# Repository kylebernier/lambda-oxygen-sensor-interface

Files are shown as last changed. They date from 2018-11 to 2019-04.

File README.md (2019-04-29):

# Lambda Oxygen Sensor Interface

This repository contains all code, pcb design, and verification scripts performed for the Lambda Oxygen Sensor Interface. This device uses a Bosch LSU 4.9 paired with a Bosch CJ125 to measure the oxygen content of an engine's exhaust. The value output by the device is the lambda value, which is the ratio between the stoichiometric air/fuel ratio and the air/fuel ratio measured by the sensor. The values output are between 0.65 and 1.36 and are proportional to 0 to 5V DC. A serial UART interface also outputs the lambda value, the temperature, and the voltage the sensor is being set to.  

## Repository Structure
- All code for the actual device can be found in the `code` folder.
- All simulations for hardware and software algortihms can be found in the `sim` folder.
- All PCB design files can be found in the `pcb` folder.
- All scripts and data for verifying results can be found in the `verification` folder.

## Reference Documents

* [STM32L476VG Datasheet](https://www.st.com/resource/en/datasheet/stm32l476vg.pdf)
* [STM32L475RC Datasheet](https://www.st.com/resource/en/datasheet/stm32l475rc.pdf)
* [STM32L4xx Reference Manual](https://www.st.com/content/ccc/resource/technical/document/reference_manual/02/35/09/0c/4f/f7/40/03/DM00083560.pdf/files/DM00083560.pdf/jcr:content/translations/en.D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)
* [STM32L4xx Hal Reference Manual](https://www.st.com/content/ccc/resource/technical/document/user_manual/63/a8/8f/e3/ca/a1/4c/84/DM00173145.pdf/files/DM00173145.pdf/jcr:content/translations/en.DM0017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)
* [CJ125 Datasheet](http://www.bosch-semiconductors.com/media/automotive_systems_ics/pdf_1/ic_engine_management/bosch_ic_cj125.pdf)
* [LSU 4.9 Datasheet](https://www.ecotrons.com/files/Bosch_LSU49_Tech_Info.pdf)

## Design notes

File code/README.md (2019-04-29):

# Code

## Code Algorithm

The code controls a STM32L4 microcontroller on a Lambda Oxygen Sensor Interface board.

### Modules Being Used
All modules and their respective GPIO pins can be found in `hw_map.h`
* ADC: ADC1 on channels 8, 11, 12, 16 
* DMA: DMA1 on channel 1
* SPI: SPI2
* DAC: DAC1 on channel 2
* PWM: TIM8 on channel 2, IRQ on channel 1
* UART: USART1

## Build Instructions

### Required Packages
* arm-none-eabi-gcc
* arm-none-eabi-gdb
* arm-none-eabi-binutils
* openOCD

### Recommended Packages
* Visual Studio Code
    * Cortex-Debug Extension

### Compiling
* Run `make`

    or

* Run `Debug STM32L4` debugger in VSCode

### Flashing
* Run `openocd -f openocd.cfg -c "program bin/main.elf verify reset exit"`

    or

* Run `Debug STM32L4` debugger in VSCode

### Debugging
* Use gdb with openOCD

    or

* Run `Debug STM32L4` debugger in VSCode

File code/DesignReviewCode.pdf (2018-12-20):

adc.c | Page 1 of 4
/**
* @file adc.c
* @author Kyle Bernier
* @author Daeghan Elkin
* @date 2018 July 15
*
* @brief Provides basic ADC functionality */

#include "stm32l4xx_ll_dma.h"

#include "adc.h"

/**
* @brief Initialize DMA for the ADC
*
* @param values Array to store ADC values
* @param numValues Number of values in values array *
* @retval None
*/
static void ADC_Init_DMA(uint16_t * values, int numValues);

/** @brief Delay between ADC end of calibration and ADC enable */
#define ADC_DELAY_CALIB_ENABLE_CPU_CYCLES (LL_ADC_DELAY_CALIB_ENABLE_ADC_CYCLES * 32)

/** @brief Number of possible ADC channels */
#define ADC_NUM_CHANNELS 24

/** @brief Array of ADC channels */ uint32_t ADC_CHANNELS[ADC_NUM_CHANNELS] = { LL_ADC_CHANNEL_0,
LL_ADC_CHANNEL_1,
LL_ADC_CHANNEL_2,
LL_ADC_CHANNEL_3,
LL_ADC_CHANNEL_4,
LL_ADC_CHANNEL_5,
LL_ADC_CHANNEL_6,
LL_ADC_CHANNEL_7,
LL_ADC_CHANNEL_8,
LL_ADC_CHANNEL_9,
LL_ADC_CHANNEL_10,
LL_ADC_CHANNEL_11,
LL_ADC_CHANNEL_12,
LL_ADC_CHANNEL_13,
LL_ADC_CHANNEL_14,
LL_ADC_CHANNEL_15,
LL_ADC_CHANNEL_16,
LL_ADC_CHANNEL_VREFINT, | // ADC1 Only, Uses Channel 0
LL_ADC_CHANNEL_TEMPSENSOR, | // ADC1 or ADC3
LL_ADC_CHANNEL_VBAT, | // ADC1 or ADC3
LL_ADC_CHANNEL_DAC1CH1_ADC2, | // ADC2 Only
LL_ADC_CHANNEL_DAC1CH2_ADC2, | // ADC2 Only
LL_ADC_CHANNEL_DAC1CH1_ADC3, | // ADC3 Only, Uses Channel 14
LL_ADC_CHANNEL_DAC1CH2_ADC3 | // ADC3 Only, Uses Channel 15
};

/** @brief Array of ADC channel ranks */
uint32_t ADC_RANKS[16] = {
LL_ADC_REG_RANK_1,
LL_ADC_REG_RANK_2,
LL_ADC_REG_RANK_3,
LL_ADC_REG_RANK_4,
LL_ADC_REG_RANK_5,
LL_ADC_REG_RANK_6,
LL_ADC_REG_RANK_7,
LL_ADC_REG_RANK_8,
LL_ADC_REG_RANK_9,
LL_ADC_REG_RANK_10,
LL_ADC_REG_RANK_11,
LL_ADC_REG_RANK_12,
LL_ADC_REG_RANK_13,

adc.c | Page 2 of 4
LL_ADC_REG_RANK_14,
LL_ADC_REG_RANK_15,
LL_ADC_REG_RANK_16
};

/**
* @brief DMA transfer value
* 0: DMA transfer is not completed @n
* 1: DMA transfer is completed @n
* 2: DMA transfer has not been started yet (initial state) */
volatile uint8_t dmaTransferStatus = 2;

/**
* @brief ADC group sequence conversion value
* 0: ADC group regular sequence conversions are not completed * 1: ADC group regular sequence conversions are completed */
volatile uint8_t adcConversionStatus = 0;

/* Initialize ADC with DMA*/
void Init_ADC(uint32_t channels, uint16_t * values, int numValues) {
int i, j;

// Check if the ADC is already enabled
if (LL_ADC_IsEnabled(ADCx_BASE)) { return;
}

// Initialize DMA for the ADC
ADC_Init_DMA(values, numValues);

// Enable ADC interrupts
// Set the ADC IRQ to a greater priority than the DMA IRQ NVIC_SetPriority(ADCx_IRQ, 0); NVIC_EnableIRQ(ADCx_IRQ);

// Enable the ADC clock
ADCx_CLK_ENABLE();

// Set the ADC clock
LL_ADC_SetCommonClock(__LL_ADC_COMMON_INSTANCE(ADCx_BASE), LL_ADC_CLOCK_SYNC_PCLK_DIV2);

// Enable the internal ADC channels LL_ADC_SetCommonPathInternalCh(__LL_ADC_COMMON_INSTANCE(ADCx_BASE), (LL_ADC_PATH_INTERNAL_VRE
FINT | LL_ADC_PATH_INTERNAL_TEMPSENSOR | LL_ADC_PATH_INTERNAL_VBAT));

// Delay for the internal ADC channels to stablize
// The temperature sensor takes the longest time to stabalize
i = ((LL_ADC_DELAY_TEMPSENSOR_STAB_US * (SystemCoreClock / (100000 * 2))) / 10); while (i != 0) {
i--;
}

// Set the ADC to have a external timer trigger source LL_ADC_REG_SetTriggerSource(ADCx_BASE, LL_ADC_REG_TRIG_EXT_TIM8_TRGO);

// Set the ADC to trigger on the rising edge LL_ADC_REG_SetTriggerEdge(ADCx_BASE, LL_ADC_REG_TRIG_EXT_RISING);

// Set the ADC to perform a single conversion LL_ADC_REG_SetContinuousMode(ADCx_BASE, LL_ADC_REG_CONV_SINGLE);

// Set the ADC conversion data transfer LL_ADC_REG_SetDMATransfer(ADCx_BASE, LL_ADC_REG_DMA_TRANSFER_UNLIMITED);

// Set the ADC overrun behavior
LL_ADC_REG_SetOverrun(ADCx_BASE, LL_ADC_REG_OVR_DATA_OVERWRITTEN);

// Set the ADC sequencer length

adc.c | Page 3 of 4
LL_ADC_REG_SetSequencerLength(ADCx_BASE, numValues - 1);

// Enable specified ADC channels
for (i = 0, j = 0; i < ADC_NUM_CHANNELS; i++) {
if (channels & (1 << i)) {
LL_ADC_REG_SetSequencerRanks(ADCx_BASE, ADC_RANKS[j], ADC_CHANNELS[i]); LL_ADC_SetChannelSamplingTime(ADCx_BASE, ADC_CHANNELS[i], ADCx_SAMPLERATE); j++;
}
if (j >= numValues || j >= 16) break;
}

// Enable ADC interupts for conversion completion LL_ADC_EnableIT_EOS(ADCx_BASE);

// Enable ADC interupts for overrun LL_ADC_EnableIT_OVR(ADCx_BASE);

// Disable the ADC deep power down mode LL_ADC_DisableDeepPowerDown(ADCx_BASE);

// Enable the ADC internal voltage regulator LL_ADC_EnableInternalRegulator(ADCx_BASE);

// Delay for the ADC internal voltage regulator to stabilize
i = ((LL_ADC_DELAY_INTERNAL_REGUL_STAB_US * (SystemCoreClock / (100000 * 2))) / 10); while (i != 0) {
i--;
}

// Start the ADC calibration LL_ADC_StartCalibration(ADCx_BASE, LL_ADC_SINGLE_ENDED);

// Wait for the ADC calibration to finish
while (LL_ADC_IsCalibrationOnGoing(ADCx_BASE) != 0);

// Delay to allow ADC calibration to enable
i = (ADC_DELAY_CALIB_ENABLE_CPU_CYCLES >> 1); while (i != 0) {
i--;
}

// Enable the ADC
LL_ADC_Enable(ADCx_BASE);

// Wait for the ADC to be ready
while (LL_ADC_IsActiveFlag_ADRDY(ADCx_BASE) == 0);

// Start the ADC conversion LL_ADC_REG_StartConversion(ADCx_BASE);
}

static void ADC_Init_DMA(uint16_t *values, int numValues) {
// Enable DMA interrupts
// Set the DMA IRQ to a lower priority than the ADC IRQ NVIC_SetPriority(DMAx_IRQ, 1); NVIC_EnableIRQ(DMAx_IRQ);

// Enable the DMA clock
DMAx_CLK_ENABLE();

// Configure the DMA transfer LL_DMA_ConfigTransfer(DMAx_BASE, DMAx_CHANNEL, LL_DMA_DIRECTION_PERIPH_TO_MEMORY | LL_DMA_MODE_CIRCULAR |
LL_DMA_PERIPH_NOINCREMENT | LL_DMA_MEMORY_INCREMENT |
LL_DMA_PDATAALIGN_HALFWORD | LL_DMA_MDATAALIGN_HALFWORD |
LL_DMA_PRIORITY_HIGH );

adc.c | Page 4 of 4
// Select ADCx_BASE as the DMA transfer request
LL_DMA_SetPeriphRequest(DMAx_BASE, DMAx_CHANNEL, LL_DMA_REQUEST_0);

// Set the DMA transfer address source and destination
LL_DMA_ConfigAddresses(DMAx_BASE, DMAx_CHANNEL, LL_ADC_DMA_GetRegAddr(ADCx_BASE, LL_ADC_DMA_REG_REGULAR_DATA), (uint32_t)values, LL_DMA_DIRECTION_PERIPH_TO_MEMORY);

// Set the DMA transfer size
LL_DMA_SetDataLength(DMAx_BASE, DMAx_CHANNEL, numValues);

// Enable DMA transfer complete interrupts LL_DMA_EnableIT_TC(DMAx_BASE, DMAx_CHANNEL);

// Enable DMA transfer error interrupts LL_DMA_EnableIT_TE(DMAx_BASE, DMAx_CHANNEL);

// Enable the DMA channel
LL_DMA_EnableChannel(DMAx_BASE, DMAx_CHANNEL); }

/* DMA transfer complete callback */
void ADC_DMA_TransferComplete_Callback(void)
{
// Update the DMA transfer status dmaTransferStatus = 1;

// Verify the ADC conversion was completed if (adcConversionStatus != 1) { ADC_DMA_TransferError_Callback();
}

// Reset the ADC conversion status adcConversionStatus = 0;
}

/* DMA transfer error callback */
void ADC_DMA_TransferError_Callback(void) {
// Handle the error
//while(1);
}

/* ADC group regular end of sequence conversions interruption callback */ void ADC_ConvComplete_Callback(void)
{
// Update the ADC conversion status
adcConversionStatus = 1;
}

/* ADC group regular overrun interruption callback */ void ADC_OverrunError_Callback(void)
{
// Disable ADC overrun interrupts LL_ADC_DisableIT_OVR(ADCx_BASE); }

dac.c | Page 1 of 1

* @file dac.c
* @author Kyle Bernier
* @author Daeghan Elkin
* @date 2018 July 29
*
* @brief Provides basic DAC functionality *
*/

#include "dac.h"

/* Initialize the DAC interface */ int Init_DAC(void)
{
volatile uint32_t i = 0;

// Enable the peripheral clock for the DAC
DACx_CLK_ENABLE();

// Set the DAC trigger source to software
LL_DAC_SetTriggerSource(DACx_BASE, DAC_LMD_CHANNEL, LL_DAC_TRIG_SOFTWARE);

// Configure the DAC output for channel 1
LL_DAC_ConfigOutput(DACx_BASE, DAC_LMD_CHANNEL, LL_DAC_OUTPUT_MODE_NORMAL, LL_DAC_OUTPUT_BUFF ER_ENABLE, LL_DAC_OUTPUT_CONNECT_GPIO);

// Enable the DMA underrun interrupt for channel 1
//LL_DAC_EnableIT_DMAUDR2(DACx_BASE);

// Enable the DAC for channel 1
LL_DAC_Enable(DACx_BASE, DAC_LMD_CHANNEL);

// Delay to allow the DAC voltage to settle
i = ((LL_DAC_DELAY_STARTUP_VOLTAGE_SETTLING_US * (SystemCoreClock / (100000 * 2))) / 10); while (i != 0)
{
i--;
}

// Enable the DAC
LL_DAC_EnableTrigger(DACx_BASE, DAC_LMD_CHANNEL);

return 0;
}

/* Adjust the DAC output value */ void DAC_SetValue(uint32_t value)
{
// Set the DAC value
LL_DAC_ConvertData12RightAligned(DACx_BASE, DAC_LMD_CHANNEL, 0xFFF & value); // Tigger a DAC conversion
LL_DAC_TrigSWConversion(DACx_BASE, DAC_LMD_CHANNEL);
}

hw_map.c | Page 1 of 2

* @file hw_map.c
* @author Kyle Bernier
* @author Daeghan Elkin
* @date 2018 September 8
*
* @brief Maps hardware peripherals to board specific features *
*/

#include "hw_map.h"

/* Initializes hardware required by peripherals */ void HW_Init_GPIO(void)
{
// Enable the clock for GPIO port A LL_AHB2_GRP1_EnableClock(LL_AHB2_GRP1_PERIPH_GPIOA);

//------------------------
// ADC Setup
//------------------------
// Enable the clock for GPIO port B LL_AHB2_GRP1_EnableClock(LL_AHB2_GRP1_PERIPH_GPIOB);

// Enable the clock for GPIO port E LL_AHB2_GRP1_EnableClock(LL_AHB2_GRP1_PERIPH_GPIOE);

// Configure the GPIO pin as a ADC input LL_GPIO_SetPinMode(ADC_BAT_GPIO_PORT, ADC_BAT_GPIO_PIN, LL_GPIO_MODE_ANALOG); // Map GPIO pin to the ADC LL_GPIO_EnablePinAnalogControl(ADC_BAT_GPIO_PORT, ADC_BAT_GPIO_PIN);

// Configure the GPIO pin as a ADC input LL_GPIO_SetPinMode(ADC_LMD_GPIO_PORT, ADC_LMD_GPIO_PIN, LL_GPIO_MODE_ANALOG); // Map GPIO pin to the ADC LL_GPIO_EnablePinAnalogControl(ADC_LMD_GPIO_PORT, ADC_LMD_GPIO_PIN);

// Configure the GPIO pin as a ADC input LL_GPIO_SetPinMode(ADC_RES_GPIO_PORT, ADC_RES_GPIO_PIN, LL_GPIO_MODE_ANALOG); // Map GPIO pin to the ADC
LL_GPIO_EnablePinAnalogControl(ADC_RES_GPIO_PORT, ADC_RES_GPIO_PIN);

// Configure the GPIO pin as a ADC input LL_GPIO_SetPinMode(ADC_CRNT_GPIO_PORT, ADC_CRNT_GPIO_PIN, LL_GPIO_MODE_ANALOG); // Map GPIO pin to the ADC
LL_GPIO_EnablePinAnalogControl(ADC_CRNT_GPIO_PORT, ADC_CRNT_GPIO_PIN);

//------------------------
// DAC Setup
//------------------------
// Configure the GPIO pin as a DAC input LL_GPIO_SetPinMode(DAC_LMD_GPIO_PORT, DAC_LMD_GPIO_PIN, LL_GPIO_MODE_ANALOG);

//-------------------------
// PWM Setup
//-------------------------
// Enable the peripheral clock of GPIOs
PWMx_GPIO_CLK_ENABLE();

// GPIO TIM configuration
LL_GPIO_SetPinMode(PWMx_GPIO_PORT, PWMx_GPIO_PIN, LL_GPIO_MODE_ALTERNATE); PWMx_SET_GPIO_AF();
LL_GPIO_SetPinSpeed(PWMx_GPIO_PORT, PWMx_GPIO_PIN, LL_GPIO_SPEED_FREQ_HIGH); LL_GPIO_SetPinOutputType(PWMx_GPIO_PORT, PWMx_GPIO_PIN, LL_GPIO_OUTPUT_PUSHPULL); LL_GPIO_SetPinPull(PWMx_GPIO_PORT, PWMx_GPIO_PIN, LL_GPIO_PULL_NO);

// Enable the timer peripheral clock
PWMx_CLK_ENABLE();

//-------------------------

hw_map.c | Page 2 of 2
// USART Setup
//-------------------------
// Enable the peripheral clock of GPIO Port
USARTx_GPIO_CLK_ENABLE();

// Configure Tx Pin
LL_GPIO_SetPinMode(USARTx_TX_GPIO_PORT, USARTx_TX_PIN, LL_GPIO_MODE_ALTERNATE); USARTx_SET_TX_GPIO_AF();
LL_GPIO_SetPinSpeed(USARTx_TX_GPIO_PORT, USARTx_TX_PIN, LL_GPIO_SPEED_FREQ_HIGH); LL_GPIO_SetPinOutputType(USARTx_TX_GPIO_PORT, USARTx_TX_PIN, LL_GPIO_OUTPUT_PUSHPULL); LL_GPIO_SetPinPull(USARTx_TX_GPIO_PORT, USARTx_TX_PIN, LL_GPIO_PULL_UP);

// Configure Rx Pin
LL_GPIO_SetPinMode(USARTx_RX_GPIO_PORT, USARTx_RX_PIN, LL_GPIO_MODE_ALTERNATE); USARTx_SET_RX_GPIO_AF();
LL_GPIO_SetPinSpeed(USARTx_RX_GPIO_PORT, USARTx_RX_PIN, LL_GPIO_SPEED_FREQ_HIGH); LL_GPIO_SetPinOutputType(USARTx_RX_GPIO_PORT, USARTx_RX_PIN, LL_GPIO_OUTPUT_PUSHPULL); LL_GPIO_SetPinPull(USARTx_RX_GPIO_PORT, USARTx_RX_PIN, LL_GPIO_PULL_UP);

// Enable USART peripheral clock and clock source
USARTx_CLK_ENABLE();

// Set clock source
USARTx_CLK_SOURCE();

//-------------------------
// SPI Setup
//-------------------------
// Enable the peripheral clock of GPIO Port
SPIx_GPIO_CLK_ENABLE();

// Configure the SPI SCK pin
LL_GPIO_SetPinMode(SPI_CJ125_SCK_PORT, SPI_CJ125_SCK_PIN, LL_GPIO_MODE_ALTERNATE); LL_GPIO_SetAFPin_8_15(SPI_CJ125_SCK_PORT, SPI_CJ125_SCK_PIN, LL_GPIO_AF_5); LL_GPIO_SetPinSpeed(SPI_CJ125_SCK_PORT, SPI_CJ125_SCK_PIN, LL_GPIO_SPEED_FREQ_HIGH); LL_GPIO_SetPinPull(SPI_CJ125_SCK_PORT, SPI_CJ125_SCK_PIN, LL_GPIO_PULL_DOWN);

// Configure the SPI MISO pin
LL_GPIO_SetPinMode(SPI_CJ125_MISO_PORT, SPI_CJ125_MISO_PIN, LL_GPIO_MODE_ALTERNATE); LL_GPIO_SetAFPin_8_15(SPI_CJ125_MISO_PORT, SPI_CJ125_MISO_PIN, LL_GPIO_AF_5); LL_GPIO_SetPinSpeed(SPI_CJ125_MISO_PORT, SPI_CJ125_MISO_PIN, LL_GPIO_SPEED_FREQ_HIGH); LL_GPIO_SetPinPull(SPI_CJ125_MISO_PORT, SPI_CJ125_MISO_PIN, LL_GPIO_PULL_DOWN);

// Configure the SPI MOSI pin
LL_GPIO_SetPinMode(SPI_CJ125_MOSI_PORT, SPI_CJ125_MOSI_PIN, LL_GPIO_MODE_ALTERNATE); LL_GPIO_SetAFPin_8_15(SPI_CJ125_MOSI_PORT, SPI_CJ125_MOSI_PIN, LL_GPIO_AF_5); LL_GPIO_SetPinSpeed(SPI_CJ125_MOSI_PORT, SPI_CJ125_MOSI_PIN, LL_GPIO_SPEED_FREQ_HIGH); LL_GPIO_SetPinPull(SPI_CJ125_MOSI_PORT, SPI_CJ125_MOSI_PIN, LL_GPIO_PULL_DOWN);

// Configure the SPI Select pin
LL_GPIO_SetPinMode(SPI_CJ125_SEL_PORT, SPI_CJ125_SEL_PIN, LL_GPIO_MODE_ALTERNATE); LL_GPIO_SetAFPin_8_15(SPI_CJ125_SEL_PORT, SPI_CJ125_SEL_PIN, LL_GPIO_AF_5); LL_GPIO_SetPinSpeed(SPI_CJ125_SEL_PORT, SPI_CJ125_SEL_PIN, LL_GPIO_SPEED_FREQ_HIGH); LL_GPIO_SetPinPull(SPI_CJ125_SEL_PORT, SPI_CJ125_SEL_PIN, LL_GPIO_PULL_DOWN);

//---------------------------------
// LED initialization
//---------------------------------
MODIFY_REG(GPIOA->MODER, GPIO_MODER_MODE8, GPIO_MODER_MODE8_0); MODIFY_REG(GPIOC->MODER, GPIO_MODER_MODE9, GPIO_MODER_MODE9_0); }

main.c | Page 1 of 8

* @file main.c
* @author Kyle Bernier
* @author Daeghan Elkin
* @date 2018 May 27
*
* @brief Runs overall control for the CJ125 and LSU4.9 sensor.
*
* This program uses the values provided by the CJ125 to maintain the temperature of
* the LSU4.9 sensor. It utilizes the calibration values seen by the CJ125 to generate a * lookup table for both Lambda and Temperature values. This removes the need for
* hard-coding a lookup table, at the expense of speed. This, however, results in more * accurate readings and control.
*/

#include "stm32l4xx.h"

#include "stm32l4xx_ll_rcc.h" #include "stm32l4xx_ll_system.h" #include "stm32l4xx_ll_utils.h" #include "arm_math.h"

#include <math.h>

#include "hw_map.h"

#include "adc.h"

#include "dac.h"

#include "pwm.h"

#include "usart.h"

#include "spi.h"

#include "cj125.h"

void Initialize_Heater(void); void SystemClock_Config(void); void Generate_Lookup_Tables(void);

/**
* @brief ADC values array.
*
* Array index pertains to: @n * 0: Internal 3V3 reference @n
* 1: Battery voltage @n
* 2: Lambda value from CJ125 @n
* 3: Sensor resistance from CJ125 @n * 4: Current sense
*/
uint16_t adc_vals[5] = {0, 0, 0, 0, 0};

/**
* @brief Lookup table for lambda values.
*
* Values are calculated and inserted into array based on all possible ADC values. */
uint16_t lambda_Lookup[4096];

/**
* @brief Lookup table for temperature values.
*
* Values are calculated and inserted into array based on all possible ADC values. */
uint16_t temp_Lookup[4096];

/**
* @brief The optimal ADC resistance value the CJ125 outputs during calibration.
*
* This value is used to generate the temperature lookup table and as the control for the PID. */
uint16_t optimal_resistance;

* @brief The optimal ADC resistance value the CJ125 outputs during calibration. *

main.c | Page 2 of 8
* This value is used to generate the lambda lookup table.
*/
uint16_t optimal_lambda;

/**
* @brief The current voltage the PWM signal is using.
*
* Used as a reference during the PID control of the PWM signal */
uint32_t currentV;

/**
* @brief Internal reference voltage of STM32.
*
* This calculation is highlighted on page 583 of the RM0351 Reference Manual. */
uint32_t VDDA;

/**
* @def CONDENSATION
* @brief Sensor resistance once condensation point has been reached.
*
* This value represents the resistance of the actual sensor as it heats up. The higher * the resistance, the hotter the sensor.
*/
#define CONDENSATION 3900

/**
* @def Kp
* @brief Proportional coefficient for the PID controller.
*
* The proportional control is proportional to the error between the desired sensor * resistance and the current resistance.
*/
#define Kp 60

/**
* @def Ki
* @brief Integral coefficient for the PID controller.
*
* The integral control is used to overcome steady state error for the P control. @n
* In general the integral component is used for accumulating the running errors until the system stabilizes.
*/
#define Ki 0.8

/**
* @def Kd
* @brief Derivative coefficient for the PID controller.
*
* The derivative control is used to prevent overshoot from the P control. @n
* In general the derivative component is used to prevent the system from overshooting the desire d result.
*/
#define Kd 0

/**
* @def PREAMBLE
* @brief Preamble signifies the start of a UART transmission. */
#define PREAMBLE 0xFFFF

/**
* @def Vbat3V3
* @brief Actual measured value for the 3V3 line on the PCB.
* This value is required to make acurate readings of the battery voltage. */
#define Vbat3V3 3286

* @brief Main program entrypoint. *

main.c | Page 3 of 8
* @return Should not return.
*/
int main(void)
{
uint8_t i = 0;
uint16_t response = 0;
uint16_t lambda, lambda_adc, temp, temp_adc; int16_t derivative, error, change;
int16_t integral = 0;
int16_t last_error = 0;
uint32_t desiredV, Vbat;
//uint64_t t1, t2, diff; // Only used for timing float pwm_duty_cycle;

// Initialize the GPIO pins
HW_Init_GPIO();

// Config the system clock to 8MHz SystemClock_Config();

// Initialize ADC on channels 0, 8, 11, 12, and 16 Init_ADC(0x11901, (uint16_t *)adc_vals, 5);
// Initialize DAC
Init_DAC();
// Initialize PWM with duty cycle of 0% Init_PWM();
// Initialize USART connection to external device Init_USART();
// Initialize SPI connection to CJ125
Init_SPI();

// Determine actual value of the 3.3V the STM is using. LL_mDelay(500);
__disable_irq();
VDDA = VREFINT_CAL_VREF*(*VREFINT_CAL_ADDR)/adc_vals[0]; __enable_irq();

// Enable cycle counter; Used for timing //CoreDebug->DEMCR |= CoreDebug_DEMCR_TRCENA_Msk; //DWT->CYCCNT = 0;
//DWT->CTRL |= DWT_CTRL_CYCCNTENA_Msk;

// Loop until CJ125 is ready. When CJ125 responds OK move on. while (response != CJ125_DIAG_REG_OK) {
response = SPI_Transfer(CJ125_DIAG_REG); LL_mDelay(200);
}

// Enter CJ125 calibration mode
response = SPI_Transfer(CJ125_CALIBRATE_MODE);
// Delay to allow CJ125 to properly calibrate LL_mDelay(2000);

// Store optimal resistance the CJ125 sees for the sensor do {
__disable_irq();
optimal_resistance = adc_vals[3];
__enable_irq();
} while (optimal_resistance > 830 || optimal_resistance < 780);

// Store optimal lambda the CJ125 sees for the sensor
do {
__disable_irq();
optimal_lambda = adc_vals[2];
__enable_irq();
} while (optimal_lambda > 1300 || optimal_lambda < 1100);

// Set CJ125 into normal operation mode with an amplification of 8 response = SPI_Transfer(CJ125_V8_MODE);
//response = SPI_Transfer(CJ125_V17_MODE);

// Set t1 to how many clock cycles have gone by

main.c | Page 4 of 8
//t1 = DWT->CYCCNT;

// Initialize heater before using it
Initialize_Heater();

// Set t2 to how many clock cycles have gone by //t2 = DWT->CYCCNT;
// Determine the amount of time passed since start
//diff = t2-t1;

// Continuous loop to read in values from CJ125, adjust heater, and output data. while(1) {
// Read lambda and temp values from CJ125
__disable_irq();
lambda_adc = adc_vals[2];
temp_adc = adc_vals[3];
__enable_irq();

// Find lambda and temp values in lookup table lambda = lambda_Lookup[lambda_adc];
temp = temp_Lookup[temp_adc];

// Output lambda value via DAC
// Contract specification only calls for 0.65 to 1.36, so all other values are capped if (lambda >= 650 && lambda < 1360) {
DAC_SetValue((lambda-650)*4096/710);
} else if (lambda >= 1360) {
DAC_SetValue(4095);
} else if (lambda < 650) { DAC_SetValue(0);
}

// Determine battery voltage
__disable_irq();
Vbat = (adc_vals[1] * Vbat3V3 / 4096) * 955 / 187; __enable_irq();

// Determine error between desired value and current value error = optimal_resistance - temp_adc;

// Set integral term
integral = integral + error;

// Set derivative term
derivative = error - last_error;

// Calculate desired change to result in 0 error
change = (Kp * error) + (Ki * integral) + (Kd * derivative);

// Set current error to last error for next loop through last_error = error;

// Set voltage based on desired change
if (currentV - change > Vbat) {
desiredV = Vbat;
} else if (currentV - change < 0) { desiredV = 0;
} else {
desiredV = currentV - change; }

// Transmit over UART every 200ms
if (i == 20) {
// Turn on LED before UART Transmit SET_BIT(GPIOC->ODR, GPIO_ODR_OD9_Msk);

// Transmit preamble before data USART_Transmit((uint8_t *)PREAMBLE, 2);

// Transmit lambda value over UART USART_Transmit((uint8_t *)(&lambda), 2);

main.c | Page 5 of 8
// Transmit temperature value over UART USART_Transmit((uint8_t *)(&temp), 2);

// Transmit Current PWM voltage USART_Transmit((uint8_t *)(&desiredV), 2);

// Turn off LED after UART transmission CLEAR_BIT(GPIOC->ODR, GPIO_ODR_OD9_Msk);

i = 0;
}

// Calculate PWM duty cycle
pwm_duty_cycle = pow((float)desiredV / Vbat, 2);
//pwm_duty_cycle = pow((float)2000 / Vbat, 2);

// Adjust PWM signal for heater so it stays at 780C LL_TIM_OC_SetCompareCH2(PWMx_BASE, LL_TIM_GetAutoReload(PWMx_BASE)*pwm_duty_cycle);

i++;
// Delay 10ms
LL_mDelay(10);
}
}

/**
* @brief System Clock Configuration.
*
* The system Clock is configured as follows :
* | System Clock source | = PLL (MSI) | @n
* | SYSCLK(Hz) | = 80000000 | @n
* | HCLK(Hz) | = 80000000 | @n
* | AHB Prescaler | = 1 | @n
* | APB1 Prescaler | = 1 | @n
* | APB2 Prescaler | = 1 | @n
* | MSI Frequency(Hz) | = 4000000 | @n
* | PLL_M | = 1 | @n
* | PLL_N | = 40 | @n
* | PLL_R | = 2 | @n
* | Flash Latency(WS) | = 4 | @n
* @retval None
*/
void SystemClock_Config(void) {
// MSI configuration and activation LL_FLASH_SetLatency(LL_FLASH_LATENCY_4);
| LL_RCC_MSI_Enable();
| while(LL_RCC_MSI_IsReady() != 1);

// Main PLL configuration and activation LL_RCC_PLL_ConfigDomain_SYS(LL_RCC_PLLSOURCE_MSI, LL_RCC_PLLM_DIV_1, 4, LL_RCC_PLLR_DIV_2);
| LL_RCC_PLL_Enable();
| LL_RCC_PLL_EnableDomain_SYS();
| while(LL_RCC_PLL_IsReady() != 1);

// Sysclk activation on the main PLL LL_RCC_SetAHBPrescaler(LL_RCC_SYSCLK_DIV_1); LL_RCC_SetSysClkSource(LL_RCC_SYS_CLKSOURCE_PLL); while(LL_RCC_GetSysClkSource() != LL_RCC_SYS_CLKSOURCE_STATUS_PLL);

| // Set APB1 & APB2 prescaler
LL_RCC_SetAPB1Prescaler(LL_RCC_APB1_DIV_1); LL_RCC_SetAPB2Prescaler(LL_RCC_APB2_DIV_1);

// Set systick to 1ms in using frequency set to 80MHz
| LL_Init1msTick(8000000);
| // Update CMSIS variable
| LL_SetSystemCoreClock(8000000);
}

* @brief Heater initialization routine

main.c | Page 6 of 8
*
* Initializes heater to a starting voltage of less than 2V during the condensation phase.
* Once past condensation phase heater voltage is ramped up at a rate of 0.4V/s until
* reaching a maximum of 13V. This is highlighted in section 1.6 of the LSU 4.9 manual. *
* @retval None
*/
void Initialize_Heater(void) { int i = 0;
float pwm_duty_cycle;
uint16_t CurADC, VbatADC, UR;
uint16_t maxCurADC = 0;
uint32_t Vbat, maxCur, res;

// Warm up heater, supply <= 2V to heater until out of condensation phase // Uses the current sense value to determine when condensation phase is over do {
// Calculate the battery voltage from the ADC
__disable_irq();
Vbat = (adc_vals[1] * Vbat3V3 / 4096) * 955 / 187; __enable_irq();

// Set initial "warm-up" voltage to 2V
currentV = 2000;

// Calculate PWM duty cycle using equation found in LSU 4.9 manual
pwm_duty_cycle = pow((float)currentV / Vbat, 2);

// Set PWM signal to equivalent of 2Vrms
LL_TIM_OC_SetCompareCH2(PWMx_BASE, LL_TIM_GetAutoReload(PWMx_BASE)*pwm_duty_cycle);

// Sample current sense ADC to determine the maximum value
for (i= 0; i < 50; i++) {
__disable_irq();
CurADC = adc_vals[4];
__enable_irq();
if (CurADC > maxCurADC) {
maxCurADC = CurADC;
__disable_irq();
VbatADC = adc_vals[1];
__enable_irq();
}
// Delay 10ms
LL_mDelay(10);
}

// Determine the actual current based on ADC values maxCur = (maxCurADC * VDDA / 4096);

// Determine the actual voltage at highest ADC value Vbat = (VbatADC * Vbat3V3 / 4096) * 955 / 187;

// Determine sensor resisitance
res = Vbat * 7 * 50 / maxCur - 23;

// Reset max current value for next loop through maxCurADC = 0;

// Delay for 500ms
LL_mDelay(50);
} while (res < CONDENSATION);

// Generate lookup tables for both lambda and temperature values Generate_Lookup_Tables();

//currentV = 8500;
// Ramp up voltage at a rate of
i = 0;
do {
// Get the current battery voltage __disable_irq();
Vbat = (adc_vals[1] * Vbat3V3 / 4096) * 955 / 187;

main.c | Page 7 of 8
__enable_irq();

// Transmit over UART every 200ms
if (i == 40) {
// Turn on LED before UART Transmit SET_BIT(GPIOC->ODR, GPIO_ODR_OD9_Msk);

// Transmit preamble before data
USART_Transmit((uint8_t *)PREAMBLE, 2);

// Transmit lambda value over UART
USART_Transmit((uint8_t *)(&lambda_Lookup[optimal_lambda]), 2);

// Transmit temperature value over UART
USART_Transmit((uint8_t *)(&temp_Lookup[optimal_resistance]), 2);

// Transmit Current PWM voltage
USART_Transmit((uint8_t *)(&currentV), 2);

// Turn off LED after UART transmission CLEAR_BIT(GPIOC->ODR, GPIO_ODR_OD9_Msk);

i = 0;
}

// Calculate duty cycle, equation from LSU 4.9 datasheet
pwm_duty_cycle = pow((float)currentV / Vbat, 2);

// Set PWM signal to equivalent of ramp up voltage RMS LL_TIM_OC_SetCompareCH2(PWMx_BASE, LL_TIM_GetAutoReload(PWMx_BASE)*pwm_duty_cycle);

// Read resistance value of sensor; Won’t be valid till 780C is hit __disable_irq();
UR = adc_vals[3];
__enable_irq();

// Ramp up voltage by 200mV/s currentV += 1;

// Delay 5ms
LL_mDelay(5);

i++;
} while (currentV < 11000 && UR > optimal_resistance);
}

/**
* @brief Generates lookup tables for lambda and temperature values
* Equations were determined by applying best fit curves to plots present in * the LSU4.9 manual. @n
* MATLAB was used to fit the plots.
*
* @retval None
*/
void Generate_Lookup_Tables(void) {
uint16_t i;
int32_t uacal, ua, urcal, ur, lambda, temp;
float ip, o2, ri;

// Determine resistance calibration value for calculations further on ur = optimal_resistance * VDDA * (365 + 187) / 365 / 4096;
urcal = -((15.5 * 0.000158 * 301) * 1000 - ur) * 17;

// Determine lambda calibration value for calculations further on uacal = optimal_lambda * VDDA * (365 + 187) / 365 / 4096;

for (i = 0; i < 4096; i++) {
// Calculate the Lambda value
ua = i * VDDA * (365 + 187) / 365 / 4096;
ip = (ua - uacal) * 1000 / (61.9 * 8); // / 1000; o2 = ip * 0.2095 / 2540;
lambda = (o2 / 3 + 1) / (1 - 4.77 * o2) * 1000;

main.c | Page 8 of 8
//lambda = (492.3 * exp(-pow((ip - 3.869) / 0.772, 2)) + 2.183 * exp(-pow((ip - 2.288) / 0.714, 2)) + 1.09 * exp(-pow((ip - 2.8) / 6.656, 2)) + 1.011 * exp(-pow((ip - 1.697) / 1.112, 2)) ) * 1000;

if (lambda >= 10119 || lambda <= 0) {
lambda = 10119;
}
// Set lambda lookup table value lambda_Lookup[i] = lambda;

// Calculate the temperature value
ur = i * VDDA * (365 + 187) / 365 / 4096; ri = (ur - urcal / 17) / (15.5 * 0.158); temp = 4445 * pow(ri, -0.4449) + 428.6;

if (temp >= 7049|| temp <= 0) {
temp = 7049;
}
// Set temperature lookup table value temp_Lookup[i] = temp;
}
}

pwm.c | Page 1 of 2

* @file pwm.c
* @author Kyle Bernier
* @author Daeghan Elkin
* @date 2018 September 9
*
* @brief Provides basic PWM functionality *
*/
#include "pwm.h"

/**
* @brief Current state of the PWM signal; 1: high, 0: low. *
* Value is set during PWM interrupts.
*/
uint8_t pwm_state = 0;

/* Initialize PWM */
void Init_PWM(void)
{
// Enable PWM interrupts
NVIC_SetPriority(PWMx_IRQ, 2);
NVIC_EnableIRQ(PWMx_IRQ);

// Set the pre-scaler value
LL_TIM_SetPrescaler(PWMx_BASE, __LL_TIM_CALC_PSC(SystemCoreClock, 100000));

// Set the auto-reload value to have a counter frequency of 100 Hz LL_TIM_SetAutoReload(PWMx_BASE, __LL_TIM_CALC_ARR(SystemCoreClock, LL_TIM_GetPrescaler(PWMx_B ASE), 100));

// Set output mode
LL_TIM_OC_SetMode(PWMx_BASE, PWMx_CHANNEL, LL_TIM_OCMODE_PWM1);
LL_TIM_OC_SetMode(PWMx_BASE, PWMx_IRQ_CHANNEL, LL_TIM_OCMODE_PWM1);

// Set external trigger to output on Capture/Compare Output Channel 1 LL_TIM_SetTriggerOutput(PWMx_BASE, LL_TIM_TRGO_OC1REF);

// Set compare value have a 0% duty cycle LL_TIM_OC_SetCompareCH2(PWMx_BASE, 0); LL_TIM_OC_SetCompareCH1(PWMx_BASE, 1);

// Enable PWM register preload. LL_TIM_OC_EnablePreload(PWMx_BASE, PWMx_CHANNEL); LL_TIM_OC_EnablePreload(PWMx_BASE, PWMx_IRQ_CHANNEL);

// Enable output channel
LL_TIM_CC_EnableChannel(PWMx_BASE, PWMx_CHANNEL); LL_TIM_CC_EnableChannel(PWMx_BASE, PWMx_IRQ_CHANNEL);

// Enable outputs
LL_TIM_EnableAllOutputs(PWMx_BASE);

// Enable the interrupts
LL_TIM_EnableIT_CC1(PWMx_BASE); LL_TIM_EnableIT_CC2(PWMx_BASE);

// Enable counter
LL_TIM_EnableCounter(PWMx_BASE);

// Force update generation LL_TIM_GenerateEvent_UPDATE(PWMx_BASE); }

/* Callback for Compare/Capture 1 Interrupt */ void TimerCC1_Callback(void) {
// Turn on LED
SET_BIT(GPIOA->ODR, GPIO_ODR_OD8_Msk);
}

/* Callback for Compare/Capture 2 Interrupt */

pwm.c | Page 2 of 2
void TimerCC2_Callback(void) {
// Turn off LED
CLEAR_BIT(GPIOA->ODR, GPIO_ODR_OD8_Msk); }

spi.c | Page 1 of 2

* @file spi.c
* @author Kyle Bernier
* @author Daeghan Elkin
* @date 2018 July 15
*
* @brief Provides basic SPI functionality *
*/

#include "spi.h"

/* Inialize the SPI interface */ void Init_SPI(void)
{
// Enable the clock for the SPI
SPIx_CLK_ENABLE();

// Configure the SPI interface
LL_SPI_SetBaudRatePrescaler(SPI_CJ125_BASE, LL_SPI_BAUDRATEPRESCALER_DIV256); LL_SPI_SetTransferDirection(SPI_CJ125_BASE,LL_SPI_FULL_DUPLEX); LL_SPI_SetClockPhase(SPI_CJ125_BASE, LL_SPI_PHASE_2EDGE); LL_SPI_SetClockPolarity(SPI_CJ125_BASE, LL_SPI_POLARITY_LOW); LL_SPI_SetDataWidth(SPI_CJ125_BASE, LL_SPI_DATAWIDTH_8BIT); LL_SPI_SetNSSMode(SPI_CJ125_BASE, LL_SPI_NSS_SOFT); LL_SPI_SetRxFIFOThreshold(SPI_CJ125_BASE, LL_SPI_RX_FIFO_TH_QUARTER); LL_SPI_SetMode(SPI_CJ125_BASE, LL_SPI_MODE_MASTER);

// Enable the SPI interface
LL_SPI_Enable(SPI_CJ125_BASE);

// Enable select line
MODIFY_REG(GPIOB->MODER, GPIO_MODER_MODE12, GPIO_MODER_MODE12_0);

// Enable reset line
MODIFY_REG(GPIOC->MODER, GPIO_MODER_MODE6, GPIO_MODER_MODE6_0); // Set SPI reset line high
SET_BIT(GPIOC->ODR, GPIO_ODR_OD6_Msk);
}

/* Complete an SPI transfer */
uint16_t SPI_Transfer(uint16_t send)
{
uint16_t recv;
//int i;

// Set SPI select line low CLEAR_BIT(GPIOB->ODR, GPIO_ODR_OD12_Msk);

//for (i = 0; i < send_size; i++) {
// Wait for TX buffer to be empty while(!LL_SPI_IsActiveFlag_TXE(SPI_CJ125_BASE));
// Reverse byte order
send = ((send << 8) & 0xff00) | ((send >> 8) & 0x00ff);
// Transmit a byte
LL_SPI_TransmitData16(SPI_CJ125_BASE, send);
// Wait for transmit to finish
while (SPI_CJ125_BASE->SR & SPI_SR_BSY); //}

//for (i = 0; i < recv_size; i++) {
// Wait for TX buffer to be empty while(!LL_SPI_IsActiveFlag_TXE(SPI_CJ125_BASE)); // Receive a byte
recv = LL_SPI_ReceiveData16(SPI_CJ125_BASE);
// Reverse byte order
recv = ((recv << 8) & 0xff00) | ((recv >> 8) & 0x00ff);
// Wait for transmit to finish
while (SPI_CJ125_BASE->SR & SPI_SR_BSY);
//}

// Set SPI select line high

spi.c | Page 2 of 2
SET_BIT(GPIOB->ODR, GPIO_ODR_OD12_Msk);

return recv;
}

stm32l4xx_it.c | Page 1 of 2

* @file stm32l4xx_it.c
* @author Kyle Bernier
* @author Daeghan Elkin
* @brief Interrupt setup for STM32L4xx * @date 2018-11-27
*/
#include "stm32l4xx.h"

#include "hw_map.h"

#include "adc.h"

#include "spi.h"

#include "pwm.h"

/* This function handles NMI exceptions */
void NMI_Handler(void) {
}

/* THis function handles Hard Fault exceptions */ void HardFault_Handler(void) {
// Enter an infinite loop
while (1);
}

/* This function handles Memory Manage exceptions */ void MemManage_Handler(void) {
// Enter an infinite loop
while (1);
}

/* This function handles Bus Fault exceptions */ void BusFault_Handler(void) {
// Enter an infinite loop
while (1);
}

/* This function handles Fault exceptions */ void UsageFault_Handler(void) {
// Enter an infinite loop
while (1);
}

/* This function handles SVCall exceptions */
void SVC_Handler(void) {
}

/* This function handles Debug Monitor exceptions */ void DebugMon_Handler(void) {
}

/* This function handles PendSVC exceptions */
void PendSV_Handler(void) {
}

/* This function handles SysTick Handlers */
void SysTick_Handler(void) {
}

/* This function handles ADC1 interrupt requests */ void ADC1_2_IRQHandler(void) {
// Check if the interupt is end of conversion if (LL_ADC_IsActiveFlag_EOS(ADCx_BASE) != 0) { // Clear the end of conversion flag LL_ADC_ClearFlag_EOS(ADCx_BASE);

// Call the ADC conversion complete callback ADC_ConvComplete_Callback();
}

// Check if the interupt is overrun
if (LL_ADC_IsActiveFlag_OVR(ADCx_BASE) != 0) {

stm32l4xx_it.c | Page 2 of 2
// Clear the ADC overrun flag LL_ADC_ClearFlag_OVR(ADCx_BASE);

// Call the ADC conversion complete callback ADC_OverrunError_Callback();
}
}

/* This function handles DMA1 interrupts requests */ void DMA1_Channel1_IRQHandler(void) {
// Check if the DMA transfer is complete
if (LL_DMA_IsActiveFlag_TC1(DMAx_BASE) == 1) { // Clear the DMA interupt flag LL_DMA_ClearFlag_GI1(DMAx_BASE);

// Call the DMA transfer complete callback ADC_DMA_TransferComplete_Callback();
}

// Check if the DMA transfer casused an error if (LL_DMA_IsActiveFlag_TE1(DMAx_BASE) == 1) { // Clear the DMA error flag LL_DMA_ClearFlag_TE1(DMAx_BASE);

// Call the DMA transfer error callback ADC_DMA_TransferError_Callback();
}
}

/* This function handles TIM8 interrupt. */ void TIM8_CC_IRQHandler(void) {
// Check whether CC1 interrupt is pending if(LL_TIM_IsActiveFlag_CC1(PWMx_BASE) == 1) {
// Clear the update interrupt flag
LL_TIM_ClearFlag_CC1(PWMx_BASE);

// Timer capture/compare interrupt processing(function defined in main.c) TimerCC1_Callback();
}

// Check whether CC2 interrupt is pending if(LL_TIM_IsActiveFlag_CC2(PWMx_BASE) == 1) {
// Clear the update interrupt flag
LL_TIM_ClearFlag_CC2(PWMx_BASE);

// Timer capture/compare interrupt processing(function defined in main.c) TimerCC2_Callback();
}
}

system_stm32l4xx.c | Page 1 of 5

******************************************************************************
* @file system_stm32l4xx.c
* @author MCD Application Team
* @brief CMSIS Cortex-M4 Device Peripheral Access Layer System Source File *
* | This file provides two functions and one global variable to be called from
* | user application:
* | - SystemInit(): This function is called at startup just after reset and
* | before branch to main program. This call is made inside
* | the "startup_stm32l4xx.s" file.
*
* | - SystemCoreClock variable: Contains the core clock (HCLK), it can be used
* | by the user application to setup the SysTick
* | timer or configure other parameters.
*
* | - SystemCoreClockUpdate(): Updates the variable SystemCoreClock and must
* | be called whenever the core clock is changed
* | during program execution.
*
* | After each device reset the MSI (4 MHz) is used as system clock source.
* | Then SystemInit() function is called, in "startup_stm32l4xx.s" file, to
* | configure the system clock before to branch to main program.
*
* This file configures the system clock as follows: *============================================================================= *-----------------------------------------------------------------------------
* | System Clock source | | MSI
*-----------------------------------------------------------------------------
* | SYSCLK(Hz) | | 4000000
*-----------------------------------------------------------------------------
* | HCLK(Hz) | | 4000000
*-----------------------------------------------------------------------------
* | AHB Prescaler | | 1
*-----------------------------------------------------------------------------
* | APB1 Prescaler | | 1
*-----------------------------------------------------------------------------
* | APB2 Prescaler | | 1
*-----------------------------------------------------------------------------
* | PLL_M | | 1
*-----------------------------------------------------------------------------
* | PLL_N | | 8
*-----------------------------------------------------------------------------
* | PLL_P | | 7
*-----------------------------------------------------------------------------
* | PLL_Q | | 2
*-----------------------------------------------------------------------------
* | PLL_R | | 2
*-----------------------------------------------------------------------------
* | PLLSAI1_P | | NA
*-----------------------------------------------------------------------------
* | PLLSAI1_Q | | NA
*-----------------------------------------------------------------------------
* | PLLSAI1_R | | NA
*-----------------------------------------------------------------------------
* | PLLSAI2_P | | NA
*-----------------------------------------------------------------------------
* | PLLSAI2_Q | | NA
*-----------------------------------------------------------------------------
* | PLLSAI2_R | | NA
*-----------------------------------------------------------------------------
* | Require 48MHz for USB OTG FS, | | Disabled
* | SDIO and RNG clock | |
*-----------------------------------------------------------------------------*============================================================================= ****************************************************************************** * @attention
*
* <h2><center>&copy; COPYRIGHT(c) 2017 STMicroelectronics</center></h2>
*
* Redistribution and use in source and binary forms, with or without modification, * are permitted provided that the following conditions are met:

system_stm32l4xx.c | Page 2 of 5
* | 1. Redistributions of source code must retain the above copyright notice,
* | this list of conditions and the following disclaimer.
* | 2. Redistributions in binary form must reproduce the above copyright notice,
* | this list of conditions and the following disclaimer in the documentation
* | and/or other materials provided with the distribution.
* | 3. Neither the name of STMicroelectronics nor the names of its contributors
* | may be used to endorse or promote products derived from this software
* | without specific prior written permission.
*
* THIS SOFTWARE IS PROVIDED BY THE COPYRIGHT HOLDERS AND CONTRIBUTORS "AS IS" * AND ANY EXPRESS OR IMPLIED WARRANTIES, INCLUDING, BUT NOT LIMITED TO, THE
* IMPLIED WARRANTIES OF MERCHANTABILITY AND FITNESS FOR A PARTICULAR PURPOSE ARE * DISCLAIMED. IN NO EVENT SHALL THE COPYRIGHT HOLDER OR CONTRIBUTORS BE LIABLE * FOR ANY DIRECT, INDIRECT, INCIDENTAL, SPECIAL, EXEMPLARY, OR CONSEQUENTIAL
* DAMAGES (INCLUDING, BUT NOT LIMITED TO, PROCUREMENT OF SUBSTITUTE GOODS OR
* SERVICES; LOSS OF USE, DATA, OR PROFITS; OR BUSINESS INTERRUPTION) HOWEVER * CAUSED AND ON ANY THEORY OF LIABILITY, WHETHER IN CONTRACT, STRICT LIABILITY, * OR TORT (INCLUDING NEGLIGENCE OR OTHERWISE) ARISING IN ANY WAY OUT OF THE USE * OF THIS SOFTWARE, EVEN IF ADVISED OF THE POSSIBILITY OF SUCH DAMAGE.
*
****************************************************************************** */

/** @addtogroup CMSIS
* @{
*/

/** @addtogroup stm32l4xx_system
* @{
*/

/** @addtogroup STM32L4xx_System_Private_Includes * @{
*/

#include "stm32l4xx.h"

#if !defined (HSE_VALUE)

#define HSE_VALUE ((uint32_t)8000000) /*!< Value of the External oscillator in Hz */ #endif /* HSE_VALUE */

#if !defined (MSI_VALUE)

#define MSI_VALUE ((uint32_t)4000000) /*!< Value of the Internal oscillator in Hz*/ #endif /* MSI_VALUE */

#if !defined (HSI_VALUE)

#define HSI_VALUE ((uint32_t)16000000) /*!< Value of the Internal oscillator in Hz*/ #endif /* HSI_VALUE */

/**
* @}
*/

/** @addtogroup STM32L4xx_System_Private_TypesDefinitions * @{
*/

/**
* @}
*/

/** @addtogroup STM32L4xx_System_Private_Defines
* @{
*/

/************************* Miscellaneous Configuration ************************/ /*!< Uncomment the following line if you need to relocate your vector Table in Internal SRAM. */
/* #define VECT_TAB_SRAM */
#define VECT_TAB_OFFSET 0x00 /*!< Vector Table base offset field.

This value must be a multiple of 0x200. */ /******************************************************************************/

system_stm32l4xx.c | Page 3 of 5

* @}
*/

/** @addtogroup STM32L4xx_System_Private_Macros * @{
*/

/**
* @}
*/

/** @addtogroup STM32L4xx_System_Private_Variables
* @{
*/
/* The SystemCoreClock variable is updated in three ways:
1) by calling CMSIS function SystemCoreClockUpdate()
2) by calling HAL API function HAL_RCC_GetHCLKFreq()
3) each time HAL_RCC_ClockConfig() is called to configure the system clock frequency Note: If you use this function to configure the system clock; then there
is no need to call the 2 first functions listed above, since SystemCoreClock variable is updated automatically.
*/
uint32_t SystemCoreClock = 4000000;

const uint8_t AHBPrescTable[16] = {0, 0, 0, 0, 0, 0, 0, 0, 1, 2, 3, 4, 6, 7, 8, 9}; const uint8_t APBPrescTable[8] = {0, 0, 0, 0, 1, 2, 3, 4};
const uint32_t MSIRangeTable[12] = {100000, 200000, 400000, 800000, 1000000, 2000000, \ 4000000, 8000000, 16000000, 24000000, 32000000, 48000000}; /**
* @}
*/

/** @addtogroup STM32L4xx_System_Private_FunctionPrototypes * @{
*/

/**
* @}
*/

/** @addtogroup STM32L4xx_System_Private_Functions * @{
*/

/**
* @brief Setup the microcontroller system. * @param None
* @retval None
*/

void SystemInit(void)
{
/* FPU settings ------------------------------------------------------------*/ #if (__FPU_PRESENT == 1) && (__FPU_USED == 1)
SCB->CPACR |= ((3UL << 10*2)|(3UL << 11*2)); /* set CP10 and CP11 Full Access */ #endif
/* Reset the RCC clock configuration to the default reset state ------------*/
/* Set MSION bit */
RCC->CR |= RCC_CR_MSION;

/* Reset CFGR register */
RCC->CFGR = 0x00000000;

/* Reset HSEON, CSSON , HSION, and PLLON bits */ RCC->CR &= (uint32_t)0xEAF6FFFF;

/* Reset PLLCFGR register */
RCC->PLLCFGR = 0x00001000;

/* Reset HSEBYP bit */
RCC->CR &= (uint32_t)0xFFFBFFFF;

system_stm32l4xx.c | Page 4 of 5

/* Disable all interrupts */
RCC->CIER = 0x00000000;

/* Configure the Vector Table location add offset address ------------------*/
#ifdef VECT_TAB_SRAM

SCB->VTOR = SRAM_BASE | VECT_TAB_OFFSET; /* Vector Table Relocation in Internal SRAM */
#else

SCB->VTOR = FLASH_BASE | VECT_TAB_OFFSET; /* Vector Table Relocation in Internal FLASH */
#endif

}

/**
* @brief Update SystemCoreClock variable according to Clock Register Values.
* | The SystemCoreClock variable contains the core clock (HCLK), it can
* | be used by the user application to setup the SysTick timer or configure
* | other parameters.
*
* @note | Each time the core clock (HCLK) changes, this function must be called
* | to update SystemCoreClock variable value. Otherwise, any configuration
* | based on this variable will be incorrect.
*
* @note | - The system frequency computed by this function is not the real
* | frequency in the chip. It is calculated based on the predefined
* | constant and the selected clock source:
*
* | - If SYSCLK source is MSI, SystemCoreClock will contain the MSI_VALUE(*)
*
* | - If SYSCLK source is HSI, SystemCoreClock will contain the HSI_VALUE(**)
*
* | - If SYSCLK source is HSE, SystemCoreClock will contain the HSE_VALUE(***)
*
* | - If SYSCLK source is PLL, SystemCoreClock will contain the HSE_VALUE(***)
* | or HSI_VALUE(*) or MSI_VALUE(*) multiplied/divided by the PLL factors.
*
* | (*) MSI_VALUE is a constant defined in stm32l4xx_hal.h file (default value
* | 4 MHz) but the real value may vary depending on the variations
* | in voltage and temperature.
*
* | (**) HSI_VALUE is a constant defined in stm32l4xx_hal.h file (default value
* | 16 MHz) but the real value may vary depending on the variations
* | in voltage and temperature.
*
* | (***) HSE_VALUE is a constant defined in stm32l4xx_hal.h file (default value
* | 8 MHz), user has to ensure that HSE_VALUE is same as the real
* | frequency of the crystal used. Otherwise, this function may
* | have wrong result.
*
* | - The result of this function could be not correct when using fractional
* | value for HSE crystal.
*
* @param None
* @retval None
*/
void SystemCoreClockUpdate(void)
{
uint32_t tmp = 0, msirange = 0, pllvco = 0, pllr = 2, pllsource = 0, pllm = 2;

/* Get MSI Range frequency--------------------------------------------------*/ if((RCC->CR & RCC_CR_MSIRGSEL) == RESET)
{ /* MSISRANGE from RCC_CSR applies */
msirange = (RCC->CSR & RCC_CSR_MSISRANGE) >> 8;
}
else
{ /* MSIRANGE from RCC_CR applies */
msirange = (RCC->CR & RCC_CR_MSIRANGE) >> 4; }
/*MSI frequency range in HZ*/
msirange = MSIRangeTable[msirange];

/* Get SYSCLK source -------------------------------------------------------*/ switch (RCC->CFGR & RCC_CFGR_SWS)

system_stm32l4xx.c | Page 5 of 5
{
case 0x00: /* MSI used as system clock source */
SystemCoreClock = msirange;
break;

case 0x04: /* HSI used as system clock source */ SystemCoreClock = HSI_VALUE;
break;

case 0x08: /* HSE used as system clock source */ SystemCoreClock = HSE_VALUE;
break;

case 0x0C: /* PLL used as system clock source */
/* PLL_VCO = (HSE_VALUE or HSI_VALUE or MSI_VALUE/ PLLM) * PLLN SYSCLK = PLL_VCO / PLLR
*/
pllsource = (RCC->PLLCFGR & RCC_PLLCFGR_PLLSRC);
pllm = ((RCC->PLLCFGR & RCC_PLLCFGR_PLLM) >> 4) + 1 ;

switch (pllsource)
{
case 0x02: /* HSI used as PLL clock source */ pllvco = (HSI_VALUE / pllm);
break;

case 0x03: /* HSE used as PLL clock source */ pllvco = (HSE_VALUE / pllm);
break;

default: /* MSI used as PLL clock source */ pllvco = (msirange / pllm);
break;
}
pllvco = pllvco * ((RCC->PLLCFGR & RCC_PLLCFGR_PLLN) >> 8); pllr = (((RCC->PLLCFGR & RCC_PLLCFGR_PLLR) >> 25) + 1) * 2; SystemCoreClock = pllvco/pllr;
break;

default:
SystemCoreClock = msirange;
break;
}
/* Compute HCLK clock frequency --------------------------------------------*/ /* Get HCLK prescaler */
tmp = AHBPrescTable[((RCC->CFGR & RCC_CFGR_HPRE) >> 4)];
/* HCLK clock frequency */
SystemCoreClock >>= tmp;
}

/**
* @}
*/

/**
* @}
*/

/**
* @}
*/

/************************ (C) COPYRIGHT STMicroelectronics *****END OF FILE****/

usart.c | Page 1 of 1

* @file usart.c
* @author Kyle Bernier
* @author Daeghan Elkin
* @date 2018 September 12
*
* @brief Provides basic USART functionality. *
*/
#include "usart.h"

/** @brief Send counter */ uint8_t ubSend = 0;

/* Initialize the USART */
void Init_USART(void) {
// Set transfer direction (Tx/Rx)
LL_USART_SetTransferDirection(USARTx_BASE, LL_USART_DIRECTION_TX_RX);

// Set 8 data bits, 1 start bit, 1 stop bit, and no parity LL_USART_ConfigCharacter(USARTx_BASE, LL_USART_DATAWIDTH_8B, LL_USART_PARITY_NONE, LL_USART_S TOPBITS_1);

// Set baud rate
LL_USART_SetBaudRate(USARTx_BASE, SystemCoreClock, LL_USART_OVERSAMPLING_16, 115200);

// Enable USART
LL_USART_Enable(USARTx_BASE);

// Polling USART initialisation
while((!(LL_USART_IsActiveFlag_TEACK(USARTx_BASE))) || (!(LL_USART_IsActiveFlag_REACK(USARTx_ BASE))));
}

/* Transmit data */
void USART_Transmit(uint8_t *send, uint8_t size) {
// Send characters one per one, until last char to be sent while (ubSend < size) {
// Wait for TXE flag to be raised
while (!LL_USART_IsActiveFlag_TXE(USARTx_BASE));

// If last char to be sent, clear TC flag
if (ubSend == (size - 1)) {
LL_USART_ClearFlag_TC(USARTx_BASE);
}

// Write character in Transmit Data register. TXE flag is cleared by writing data in TDR re gister
LL_USART_TransmitData8(USARTx_BASE, send[ubSend++]);
}

// Wait for TC flag to be raised for last char
while (!LL_USART_IsActiveFlag_TC(USARTx_BASE));

// Transmission is over, reset send amount ubSend = 0;
}

adc.h | Page 1 of 2

* @file adc.h
* @author Kyle Bernier
* @author Daeghan Elkin
* @date 2018 July 15
*
* @brief Provides ADC functionality */

#ifndef __ADC_H

#define __ADC_H

#include "hw_map.h"

/**
* @brief Initialize the ADC with DMA
*
* Initialization of the desired channels is done by taking the reverse of * the binary expansion of the channels.
* ie. Enabling channels 3, 8, 11, & 12 the representation would be:
* - - - 16 15 14 13 12 11 10 9 8 7 6 5 4 3 2 1 0
* 0 0 0 0| 0 0 0 1| 1 0 0 1|0 0 0 0|1 0 0 0
*
* Which results in a hexidecimal number of 0x01908 *
* @param channels ADC channels to read from
* @param values Array to store ADC values
* @param numValues Number of values in values array *
* @retval None
*/
void Init_ADC(uint32_t channels, uint16_t * values, int numValues);

/**
* @brief DMA transfer complete callback
*
* @note This function is executed when the transfer complete interrupt
* | is generated
*
* @retval None
*/
void ADC_DMA_TransferComplete_Callback(void);

/**
* @brief DMA transfer error callback
*
* @note | This function is executed when the transfer error interrupt
* | is generated during DMA transfer
*
* @retval None
*/
void ADC_DMA_TransferError_Callback(void);

/**
* @brief ADC group regular end of sequence conversions interruption callback *
* @note This function is executed when the ADC group regular
* | sequencer has converted all ranks of the sequence.
*
* @retval None
*/
void ADC_ConvComplete_Callback(void);

/**
* @brief ADC group regular overrun interruption callback *
* @note This function is executed when ADC group regular
* | overrun error occurs.
*
* @retval None
*/
void ADC_OverrunError_Callback(void);

adc.h | Page 2 of 2

#endif // __ADC_H

cj125.h | Page 1 of 1

* @file cj125.h
* @author Kyle Bernier
* @author Daeghan Elkin
* @brief Definitons for the CJ125 registers * @date 2018-11-27
*
*/

/**
* @defgroup CJ125 CJ125 Register definitions
* @{
*/

/** @brief Register value for identification request */
#define CJ125_IDENT_REG | 0x4800

/** @brief Register value for diagnostic request */
#define CJ125_DIAG_REG | 0x7800

/** @brief Diagnostic response from CJ125: Ready */
#define CJ125_DIAG_REG_OK | 0x28ff

/** @brief Diagnostic response from CJ125: No/Low power */ #define CJ125_DIAG_REG_NOPWR 0x2855
/** @brief Diagnostic response from CJ125: No sensor */
#define CJ125_DIAG_REG_NOSNSR 0x287f

/** @brief Register value for setting CJ125 into calibration mode */ #define CJ125_CALIBRATE_MODE 0x569d
/** @brief Register value for setting CJ125 into V=8 mode */
#define CJ125_V8_MODE | 0x5688

/** @brief Register value for setting CJ125 into V=17 mode */
#define CJ125_V17_MODE | 0x5689

/** @} */

dac.h | Page 1 of 1

* @file dac.h
* @author Kyle Bernier
* @author Daeghan Elkin
* @date 2018 July 29
*
* @brief Provides basic DAC functionality *
*/

#ifndef __DAC_H

#define __DAC_H

#include "hw_map.h"

/**
* @brief Initialize the DAC interface * @retval None
*/
int Init_DAC(void);

/**
* @brief Adjust the DAC output value
* @param value Value to set the DAC output to * @retval None
*/
void DAC_SetValue(uint32_t value);

#endif // __DAC_H

hw_map.h | Page 1 of 4

* @file hw_map.h
* @author Kyle Bernier
* @author Daeghan Elkin
* @date 2018 July 15
*
* @brief Maps hardware peripherals to board specific features *
* Sets up definitions required for hardware peripherals.
*
* Includes: ADC, DAC, DMA, PWM, UART, SPI
*/

#ifndef __HW_MAP_H

#define __HW_MAP_H

#include "stm32l4xx_ll_gpio.h" #include "stm32l4xx_ll_adc.h" #include "stm32l4xx_ll_dma.h" #include "stm32l4xx_ll_dac.h" #include "stm32l4xx_ll_tim.h" #include "stm32l4xx_ll_usart.h" #include "stm32l4xx_ll_rcc.h" #include "stm32l4xx_ll_spi.h" #include "stm32l4xx_ll_bus.h"

/**
* @defgroup ADC ADC Definitions */

/**
* @def ADCx_BASE
* @ingroup ADC
* @brief ADC channel used for all. */
#define ADCx_BASE ADC1

/**
* @def ADCx_SAMPLERATE
* @ingroup ADC
* @brief ADC sample rate
*/
#define ADCx_SAMPLERATE LL_ADC_SAMPLINGTIME_640CYCLES_5

/**
* @def ADCx_IRQ
* @ingroup ADC
* @brief STM ADC interrupt */
#define ADCx_IRQ ADC1_2_IRQn

/**
* @defgroup ADC_BAT ADC Battery Voltage Monitor
* @ingroup ADC
* @brief ADC channel used to monitor battery voltage
*
* These definitions are for the ADC that reads the current battery voltage. *
* @{
*/
/** @brief STM ADC GPIO Pin*/ #define ADC_BAT_GPIO_PIN LL_GPIO_PIN_3 /** @brief STM ADC GPIO Port*/
#define ADC_BAT_GPIO_PORT GPIOA

/** @brief STM ADC Channel*/
#define ADC_BAT_CHANNEL LL_ADC_CHANNEL_8 /** @} */

* @defgroup ADC_LMD ADC Lambda Value Monitor * @ingroup ADC
* @brief ADC channel used to read lambda value

hw_map.h | Page 2 of 4
*
* These definitions are for the ADC that reads the lambda value from the CJ125.
*
* @{
*/
/** @brief STM ADC GPIO Pin*/ #define ADC_LMD_GPIO_PIN LL_GPIO_PIN_6 /** @brief STM ADC GPIO Port*/
#define ADC_LMD_GPIO_PORT GPIOA

/** @brief STM ADC Channel*/
#define ADC_LMD_CHANNEL LL_ADC_CHANNEL_11 /** @} */

/**
* @defgroup ADC_RES ADC Resistance Monitor
* @ingroup ADC
* @brief ADC channel used to read sensor resitance
*
* These definitions are for the ADC that reads the oxygen sensor resistance * from the CJ125.
*
* @{
*/
/** @brief STM ADC GPIO Pin */ #define ADC_RES_GPIO_PIN LL_GPIO_PIN_7 /** @brief STM ADC GPIO Port */
#define ADC_RES_GPIO_PORT GPIOA

/** @brief STM ADC Channel */
#define ADC_RES_CHANNEL LL_ADC_CHANNEL_12 /** @} */

/**
* @defgroup ADC_CRNT ADC PWM Current Sense * @ingroup ADC
* @brief ADC channel used to sense current *
* @{
*/
/** @brief STM ADC GPIO Pin */ #define ADC_CRNT_GPIO_PIN LL_GPIO_PIN_1 /** @brief STM ADC GPIO Port */
#define ADC_CRNT_GPIO_PORT GPIOB

/** @brief STM ADC Channel */
#define ADC_CRNT_CHANNEL LL_ADC_CHANNEL_16 /** @} */

/**
* @def ADCx_CLK_ENABLE()
* @ingroup ADC
* @brief ADC definition for enabling peripheral clock.
*/
#define ADCx_CLK_ENABLE() LL_AHB2_GRP1_EnableClock(LL_AHB2_GRP1_PERIPH_ADC)

/**
* @defgroup DMA DMA Definitions
*/

/**
* @defgroup DMA_ADC ADC DMA
* @ingroup DMA
* @{
*/
/** @brief STM DMA */
#define DMAx_BASE DMA1

/** @brief STM DMA Channel */ #define DMAx_CHANNEL LL_DMA_CHANNEL_1 /** @brief DMA Interrupt */
#define DMAx_IRQ DMA1_Channel1_IRQn /** @} */

* @def DMAx_CLK_ENABLE()

hw_map.h | Page 3 of 4
* @ingroup DMA
* @brief Enable DMA peripheral clock
*/
#define DMAx_CLK_ENABLE() LL_AHB1_GRP1_EnableClock(LL_AHB1_GRP1_PERIPH_DMA1);

/**
* @defgroup DAC DAC Definitions
*/

/**
* @def DACx_BASE
* @ingroup DAC
* @brief STM DAC
*/
#define DACx_BASE DAC1

/**
* @defgroup DAC_LMD DAC Lambda Output * @ingroup DAC
* @{
*/
/** @brief STM DAC GPIO Pin */ #define DAC_LMD_GPIO_PIN LL_GPIO_PIN_5 /** @brief STM DAC GPIO Port */ #define DAC_LMD_GPIO_PORT GPIOA
/** @brief STM DAC Channel */
#define DAC_LMD_CHANNEL LL_DAC_CHANNEL_2 /** @} */

/**
* @defgroup DAC_CLK DAC Clock
* @ingroup DAC
* @{
*/
/** @brief Enable DAC peripheral clock */
#define DACx_CLK_ENABLE() LL_APB1_GRP1_EnableClock(LL_APB1_GRP1_PERIPH_DAC1) /** @} */

/**
* @defgroup PWM PWM Definitions * @{
*/
/** @brief STM PWM timer */
#define PWMx_BASE TIM8

/** @brief STM PWM Timer channel */ #define PWMx_CHANNEL LL_TIM_CHANNEL_CH2 /** @brief STM PWM Timer Interrupt */ #define PWMx_IRQ TIM8_CC_IRQn
/** @brief STM PWM Interrupt channel */
#define PWMx_IRQ_CHANNEL LL_TIM_CHANNEL_CH1

/** @brief Enable PWM peripheral clock */
#define PWMx_CLK_ENABLE() LL_APB2_GRP1_EnableClock(LL_APB2_GRP1_PERIPH_TIM8)

/** @brief Enable GPIO clock */
#define PWMx_GPIO_CLK_ENABLE() LL_AHB2_GRP1_EnableClock(LL_AHB2_GRP1_PERIPH_GPIOC) /** @brief STM PWM GPIO Pin */

#define PWMx_GPIO_PIN LL_GPIO_PIN_7

/** @brief STM PWM GPIO Port */
#define PWMx_GPIO_PORT GPIOC

/** @brief Set PWM alternative function */
#define PWMx_SET_GPIO_AF() LL_GPIO_SetAFPin_0_7(GPIOC, LL_GPIO_PIN_7, LL_GPIO_AF_3) /** @} */

/**
* @defgroup USART USART Definitions
* @{
*/
/** @brief STM USART */
#define USARTx_BASE USART1

/** @brief Enable peripheral clock */

hw_map.h | Page 4 of 4
#define USARTx_CLK_ENABLE() LL_APB2_GRP1_EnableClock(LL_APB2_GRP1_PERIPH_USART1)

/** @brief Set USART clock source */
#define USARTx_CLK_SOURCE() LL_RCC_SetUSARTClockSource(LL_RCC_USART1_CLKSOURCE_PCLK2)

/** @brief Enable GPIO clock */
#define USARTx_GPIO_CLK_ENABLE() LL_AHB2_GRP1_EnableClock(LL_AHB2_GRP1_PERIPH_GPIOA) /** @brief STM USART Transmit GPIO Pin */

#define USARTx_TX_PIN LL_GPIO_PIN_9

/** @brief STM USART Transmit GPIO Port */
#define USARTx_TX_GPIO_PORT GPIOA

/** @brief Set Transmit alternative function */
#define USARTx_SET_TX_GPIO_AF() LL_GPIO_SetAFPin_8_15(GPIOA, LL_GPIO_PIN_9, LL_GPIO_AF_7) /** @brief STM USART Receive GPIO Pin */

#define USARTx_RX_PIN LL_GPIO_PIN_10

/** @brief STM USART Receive GPIO Port */
#define USARTx_RX_GPIO_PORT GPIOA

/** @brief Set Receive alternative function */
#define USARTx_SET_RX_GPIO_AF() LL_GPIO_SetAFPin_8_15(GPIOA, LL_GPIO_PIN_10, LL_GPIO_AF_7) /** @} */

/**
* @defgroup SPI SPI Definitions
* @{
*/
/** @brief Enable GPIO clock */
#define SPIx_GPIO_CLK_ENABLE() LL_AHB2_GRP1_EnableClock(LL_AHB2_GRP1_PERIPH_GPIOB) /** @brief Enable peripheral clock */

#define SPIx_CLK_ENABLE() LL_APB1_GRP1_EnableClock(LL_APB1_GRP1_PERIPH_SPI2); /** @brief STM SPI */

#define SPI_CJ125_BASE SPI2

/** @brief STM SPI Clock GPIO Pin */
#define SPI_CJ125_SCK_PIN LL_GPIO_PIN_13 /** @brief STM SPI Clock GPIO Port */ #define SPI_CJ125_SCK_PORT GPIOB

/** @brief STM SPI MISO GPIO Pin */ #define SPI_CJ125_MISO_PIN LL_GPIO_PIN_14 /** @brief STM SPI MISO GPIO Port */ #define SPI_CJ125_MISO_PORT GPIOB
/** @brief STM SPI MOSI GPIO Pin */ #define SPI_CJ125_MOSI_PIN LL_GPIO_PIN_15 /** @brief STM SPI MOSI GPIO Port */ #define SPI_CJ125_MOSI_PORT GPIOB
/** @brief STM SPI Select GPIO Pin */ #define SPI_CJ125_SEL_PIN LL_GPIO_PIN_12 /** @brief STM SPI Select GPIO Port */ #define SPI_CJ125_SEL_PORT GPIOB
/** @} */

/**
* @brief Initializes hardware required by peripherals * @retval None
*/
void HW_Init_GPIO(void);

#endif // __HW_MAP_H

pwm.h | Page 1 of 1

* @file pwm.h
* @author Kyle Bernier
* @author Daeghan Elkin
* @date 2018 September 9
*
* @brief Provides basic PWM functionality *
*/
#ifndef __PWM_H

#define __PWM_H

#include "hw_map.h"

/**
* @brief Initialize PWM
*
* Sets up the PWM peripheral. The PWM has a counter rate of 100Hz. * Because the PWM signal is used to control the sensor heater, it * is initialized to a 0% duty cycle. The Timer for PWM is also used * to trigger ADC conversions so the Capture/Compare Channel 1 is set * accordingly.
*
* @retval None
*/
void Init_PWM(void);

/**
* @brief This function handles timer Compare/Capture 1 interrupt. *
* This handler simply turns on the LED on PA8.
*
* @retval None
*/
void TimerCC1_Callback(void);

/**
* @brief This function handles timer Compare/Capture 2 interrupt. *
* This handler simply turns off the LED on PA8.
*
* @retval None
*/
void TimerCC2_Callback(void);

#endif /* __PWM_H */

spi.h | Page 1 of 1

* @file spi.h
* @author Kyle Bernier
* @author Daeghan Elkin
* @date 2018 July 15
*
* @brief Provides basic SPI functionality *
*/

#ifndef __SPI_H

#define __SPI_H

#include "hw_map.h"

/**
* @brief Initialize the SPI Interface *
* @retval None
*/
void Init_SPI(void);

/**
* @brief Complete an SPI Transfer *
* @param send Value to send
*
* @returns Received data
*/
uint16_t SPI_Transfer(uint16_t send);

#endif // __SPI_H

stm32l4xx_it.h | Page 1 of 2

* @file stm32l4xx_it.h
*
*/
#ifndef __STM32L4XX_IT_H

#define __STM32L4XX_IT_H

/**
* @brief This function handles NMI exception. * @retval None
*/
void NMI_Handler(void);

/**
* @brief This function handles Hard Fault exception. * @retval None
*/
void HardFault_Handler(void);

/**
* @brief This function handles Memory Manage exception. * @retval None
*/
void MemManage_Handler(void);

/**
* @brief This function handles Bus Fault exception. * @retval None
*/
void BusFault_Handler(void);

/**
* @brief This function handles Usage Fault exception. * @retval None
*/
void UsageFault_Handler(void);

/**
* @brief This function handles SVCall exception. * @retval None
*/
void SVC_Handler(void);

/**
* @brief This function handles Debug Monitor exception. * @retval None
*/
void DebugMon_Handler(void);

/**
* @brief This function handles PendSVC exception. * @retval None
*/
void PendSV_Handler(void);

/**
* @brief This function handles SysTick Handler. * @retval None
*/
void SysTick_Handler(void);

/**
* @brief This function handles ADC1 interrupt request. * @retval None
*/
void ADC1_2_IRQHandler(void);

* @brief This function handles DMA1 interrupt request. * @retval None
*/

stm32l4xx_it.h | Page 2 of 2
void DMA1_Channel1_IRQHandler(void);

/**
* @brief This function handles TIM2 interrupt.
* @retval None
*/
void TIM8_CC_IRQHandler(void);

#endif // __STM32L4XX_IT_H

usart.h | Page 1 of 1

* @file usart.h
* @author Kyle Bernier
* @author Daeghan Elkin
* @date 2018 September 12
*
* @brief Provides basic USART functionality. *
*/

#ifndef __USART_H

#define __USART_H

#include "hw_map.h"

/**
* @brief Initializes the USART.
*
* The USART initialization sets the UART to a TX/RX transmisson.
* The UART has the typical 8 data, 1 start, and 1 stop bits with no parity. * The baudrate for the UART is set to 115200.
*
* @retval None
*/
void Init_USART();

/**
* @brief Transfers data over the transmit line.
*
* The UART is set up to handle both transmit and receive, however, * nothing is done with the received data. The receive line is
* available for future changes.
*
* @param send Array of desired send data
* @param size Size of data array
* @retval None
*/
void USART_Transmit(uint8_t *send, uint8_t size);

#endif /* __USART_H */

Makefile | Page 1 of 2
# @file Makefile

# @author Kyle Bernier and Daeghan Elkin

# @date 2018 May 27

# @brief Makefile to compile STM32L4 project with dependencies

# System configuration

CC = arm-none-eabi-gcc
RM = rm -f
MKDIR = mkdir -p

# Hardware architecture

ARCH = STM32L475xx
ARCH_LOW = stm32l475xx

# Assembler, Compiler and Linker flags and linker script settings

LINKER_FLAGS = -lm -mthumb -mhard-float -mcpu=cortex-m4 -mfpu=fpv4-sp-d16 -Wl,--gc-sections -T$(L INK_SCRIPT) -static -Wl,--start-group -lc -lm -Wl,--end-group -specs=nano.specs -specs=nosys.spec s
LINK_SCRIPT = linker_script.ld
ASSEMBLER_FLAGS = -c -g -O0 -mcpu=cortex-m4 -mfpu=fpv4-sp-d16 -mthumb -mhard-float -specs=nano.sp ecs -D"$(ARCH)" -D"ARM_MATH_CM4" -D"__FPU_PRESENT" -x assembler-with-cpp $(INCLUDE_FLAGS) COMPILER_FLAGS = -c -g -mcpu=cortex-m4 -mfpu=fpv4-sp-d16 -O0 -Wall -ffunction-sections -fdata-sec tions -mthumb -mhard-float -specs=nano.specs -D"$(ARCH)" -D"STM32L4" -D"USBD_SOF_DISABLED" -D"ARM _MATH_CM4" -D"__FPU_PRESENT" $(INCLUDE_FLAGS)

# Define directories

BIN_DIR = bin
SRC_DIR = src
LIB_DIR = lib

# CMSIS directories

CMSIS_DIR = $(LIB_DIR)/cmsis CMSIS_DEV_DIR = $(CMSIS_DIR)/device CMSIS_INC_DIR = $(CMSIS_DIR)/inc CMSIS_SRC_DIR = $(CMSIS_DIR)/src

# FreeRTOS directories

#FREERTOS_DIR = $(LIB_DIR)/freertos #FREERTOS_INC_DIR = $(FREERTOS_DIR)/include #FREERTOS_PRT_DIR = $(FREERTOS_DIR)/portable

# HAL directories

HAL_DIR = $(LIB_DIR)/hal
HAL_INC_DIR = $(HAL_DIR)/inc
HAL_SRC_DIR = $(HAL_DIR)/src

# libUSB_stm32 directories LIBUSB_DIR = $(LIB_DIR)/libusb_stm32 LIBUSB_INC_DIR = $(LIBUSB_DIR)/inc

LIBUSB_SRC_DIR = $(LIBUSB_DIR)/src

# Define include flags

INCLUDE_FLAGS = -I$(SRC_DIR) -I$(CMSIS_DEV_DIR) -I$(CMSIS_INC_DIR) -I$(CMSIS_SRC_DIR) -I$(HAL_DIR ) -I$(HAL_INC_DIR) -I$(HAL_SRC_DIR) -I$(LIBUSB_DIR) -I$(LIBUSB_INC_DIR) -I$(LIBUSB_SRC_DIR)

# Define sources

SRCS := $(wildcard $(HAL_SRC_DIR)/*.c) \
$(wildcard $(HAL_SRC_LEG_DIR)/*.c) \ $(wildcard $(SRC_DIR)/*.c) \ $(wildcard $(CMSIS_SRC_DIR)/*.c) \ $(wildcard $(LIBUSB_SRC_DIR)/*.c) SRCSASM := $(CMSIS_SRC_DIR)/startup_$(ARCH_LOW).s

HDRS := $(wildcard $(HAL_INS_DIR)/*.h) \ $(wildcard $(SRC_DIR)/*.h) \ $(wildcard $(CMSIS_INC_DIR)/*.h) \ $(wildcard $(CMSIS_DEV_DIR)/*.h) \ $(wildcard $(LIBUSB_INC_DIR)/*.h)

# Define objects

Makefile | Page 2 of 2
OBJS := $(SRCSASM:%.s=$(BIN_DIR)/%.o) $(SRCS:%.c=$(BIN_DIR)/%.o)

# Define the target file

TARGET = $(BIN_DIR)/main

all: $(TARGET)

# Link the objects into the target $(TARGET): $(OBJS) $(HDRS)

$(CC) -o $@ $(OBJS) $(LINKER_FLAGS)

# Compile c files

$(BIN_DIR)/%.o: %.c
$(MKDIR) -p $(dir $@) 2> /dev/null $(CC) $(COMPILER_FLAGS) $< -o $@

# Compile assembly files

$(BIN_DIR)/%.o: %.s
$(MKDIR) -p $(dir $@) 2> /dev/null $(CC) $(ASSEMBLER_FLAGS) $< -o $@

# Remove only src directory object files clean:

$(RM) $(wildcard $(BIN_DIR)/$(SRC_DIR)/*.o)

# Remove all object files and the target cleaner:

$(RM) $(OBJS) $(TARGET)

readdata.py | Page 1 of 2
import serial
import struct
import statistics as stat
import matplotlib.pyplot as plt import matplotlib.animation as anim from collections import deque

# Connect to the USB serial device ser = serial.Serial(’/dev/ttyUSB0’) ser.baudrate = 115200

ser.flushInput()

# Create the lambda and temp arrays for graphing lamb = deque([0] * 100);

temp = deque([0] * 100);
pwmv = deque([0] * 100);
x = range(100);

# Create the plots

fig, ax1 = plt.subplots()

# Plot Lambda

ax1.set_xlabel(’time (s)’) ax1.set_ylabel(’Lambda (mLam)’, color=’tab:blue’) ax1.plot(x, lamb, color=’tab:blue’) ax1.tick_params(axis=’y’, labelcolor=’tab:blue’) ax1.set_ylim(0, 10200)

# Create a second axes

ax2 = ax1.twinx()
# Plot Temperature

ax2.set_ylabel(’Temperature (C)’, color=’tab:red’) ax2.plot(x, temp, color=’tab:red’) ax2.tick_params(axis=’y’, labelcolor=’tab:red’) ax2.set_ylim(0, 1200)

# Create a third axes

ax3 = ax1.twinx()
# Plot Temperature

ax3.set_ylabel(’PWM Vrms(V)’, color=’tab:green’) ax3.plot(x, pwmv, color=’tab:green’) ax3.tick_params(axis=’y’, labelcolor=’tab:green’) ax3.set_ylim(0, 12)
ax3.spines["right"].set_position(("axes", 1.2)) ax3.spines["right"].set_visible(True)

fig.tight_layout()
fig.show()

# Flush the serial input of buffered data ser.flushInput()

# Graph data forever

while True:
# Check for preamble

while True:
rdbytes = ser.read(1)
if rdbytes == b’\xff’:
rdbytes = ser.read(1)
if rdbytes == b’\xff’:
break
# Read data

rdbytes = ser.read(6)
# Convert bytes to integers

values = struct.unpack(’<HHH’, rdbytes) # Insert the lambda value into the array lamb.popleft()
lamb.append(values[0]/1000)
# Insert the temperature value into the array temp.popleft()

temp.append(values[1])
# Insert the PWM Vrms value into the array pwmv.popleft()

readdata.py | Page 2 of 2
pwmv.append(values[2]/1000)
# Print the lambda value the temperature and the PWM Vrms

print(values)
# Clear the plots and replot

ax1.cla()
ax2.cla()
ax3.cla()
ax1.set_ylabel(’Lambda Value’, color=’tab:blue’) ax2.set_ylabel(’Temperature (C)’, color=’tab:red’) ax3.set_ylabel(’PWM Vrms (V)’, color=’tab:green’) ax1.plot(x, lamb, color=’tab:blue’)
ax2.plot(x, temp, color=’tab:red’)
ax3.plot(x, pwmv, color=’tab:green’)
# Reset the axes

ax1.set_ylim(0, max(lamb)+0.5) ax2.set_ylim(0, max(temp)+200) ax3.set_ylim(0, max(pwmv)+1) ax3.spines["right"].set_position(("axes", 1.2))
ax3.spines["right"].set_visible(True)
# Print imformation about each plot

ax1.text(0.01, 0.04, ’Current Lambda: ’ + str(lamb[-1]), verticalalignment=’bottom’, horizont alalignment=’left’, transform=ax2.transAxes, color=’blue’, fontsize=12)
ax1.text(0.01, 0.01, ’Mean Lambda: ’ + str(stat.mean(lamb)), verticalalignment=’bottom’, hori zontalalignment=’left’, transform=ax2.transAxes, color=’blue’, fontsize=12)
ax2.text(0.01, 0.13, ’Current Temp: ’ + str(temp[-1]) + ’C’, verticalalignment=’bottom’, hori zontalalignment=’left’, transform=ax2.transAxes, color=’red’, fontsize=12)
ax2.text(0.01, 0.10, ’Max Temp: ’ + str(max(temp)) + ’C’, verticalalignment=’bottom’, horizon talalignment=’left’, transform=ax2.transAxes, color=’red’, fontsize=12)
ax2.text(0.01, 0.07, ’Min Temp: ’ + str(min(temp)) + ’C’, verticalalignment=’bottom’, horizon talalignment=’left’, transform=ax2.transAxes, color=’red’, fontsize=12)
ax3.text(0.01, 0.16, ’Current PWM Vrms: ’ + str(pwmv[-1]) + ’V’, verticalalignment=’bottom’, horizontalalignment=’left’, transform=ax2.transAxes, color=’green’, fontsize=12)
# Draw the updated plot

fig.canvas.draw()
fig.canvas.flush_events()

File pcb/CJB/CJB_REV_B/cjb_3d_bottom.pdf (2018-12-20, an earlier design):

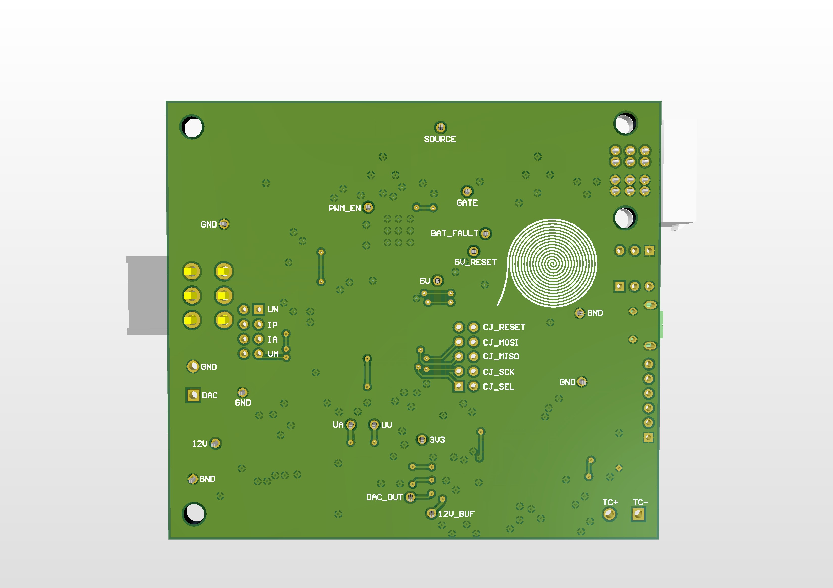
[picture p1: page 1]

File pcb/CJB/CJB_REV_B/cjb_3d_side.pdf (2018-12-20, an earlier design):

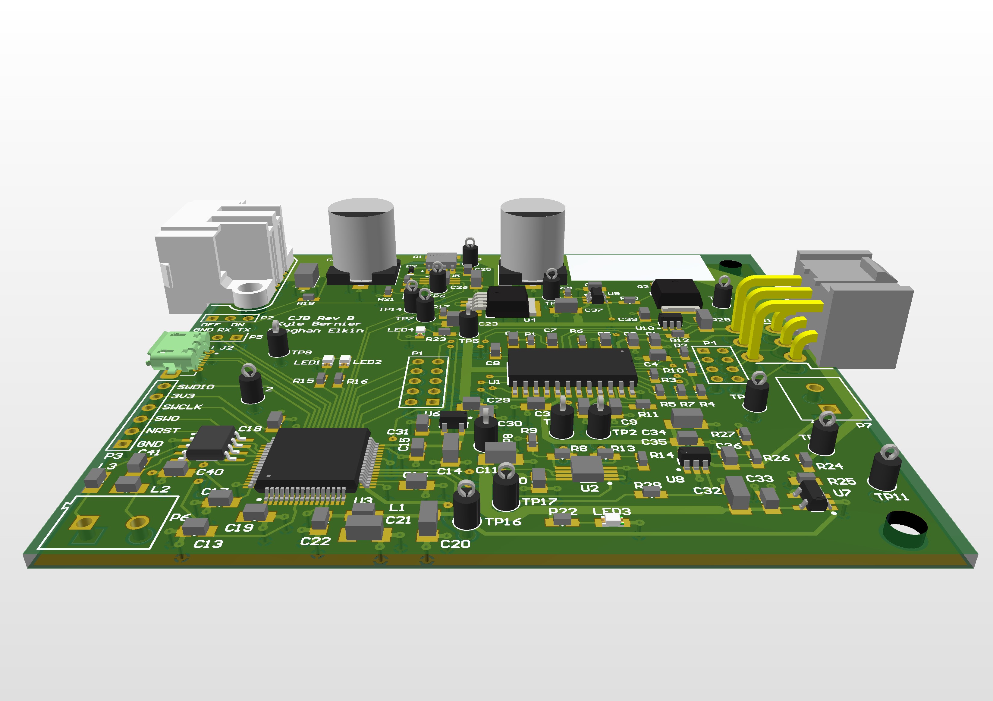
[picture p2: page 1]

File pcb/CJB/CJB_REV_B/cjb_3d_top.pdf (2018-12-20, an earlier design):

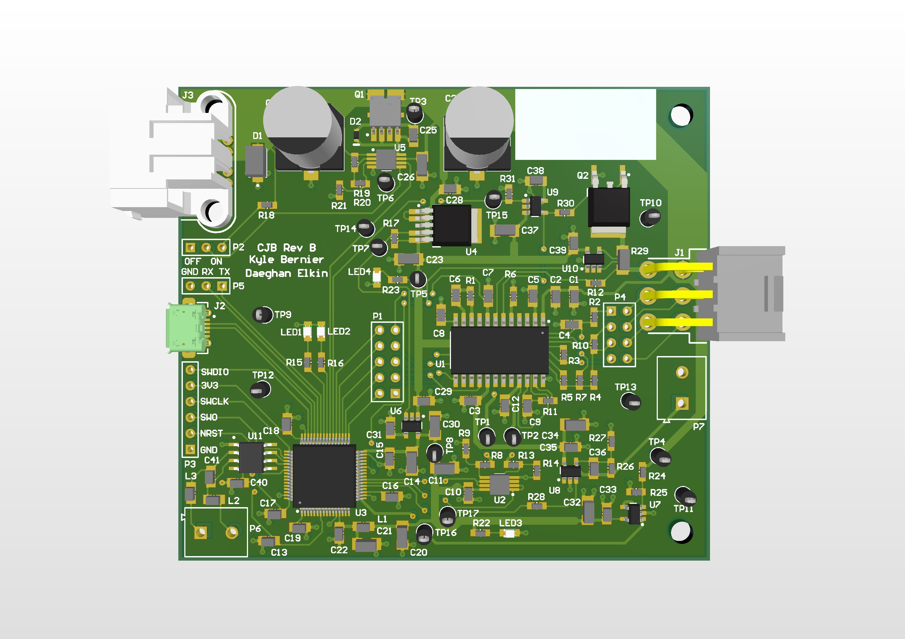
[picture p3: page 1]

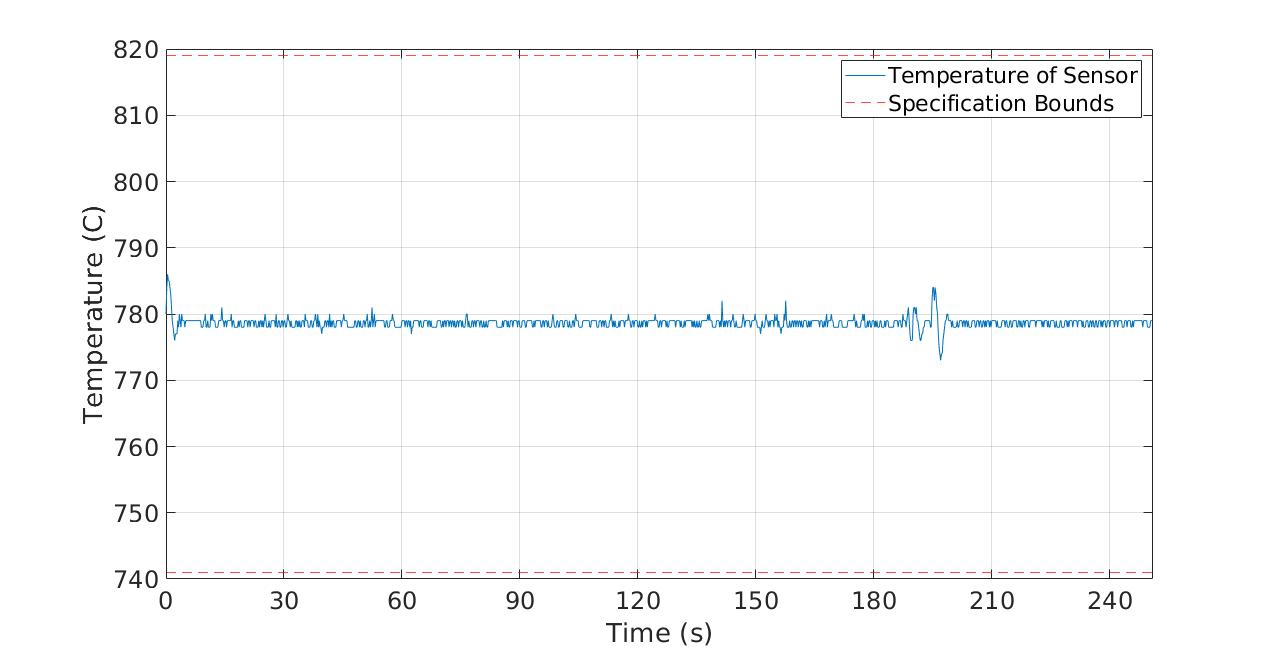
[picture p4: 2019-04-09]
verification/TemperatureSpec.jpg

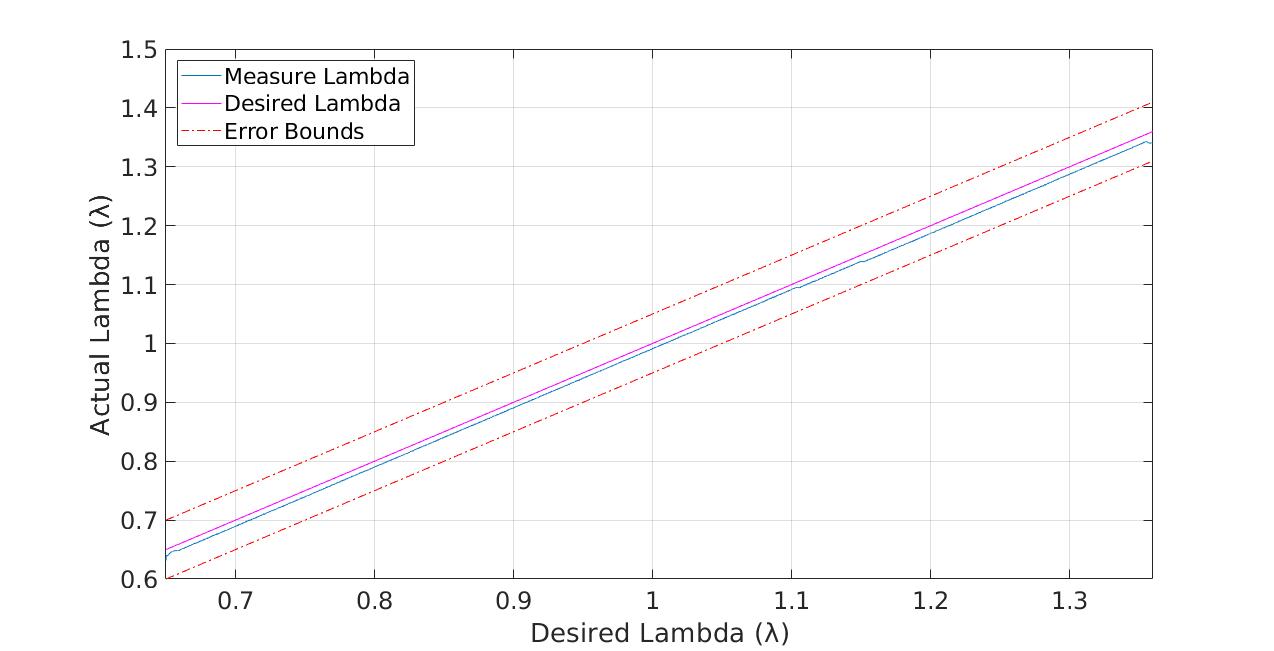
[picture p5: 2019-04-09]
verification/LambdaSpec.jpg

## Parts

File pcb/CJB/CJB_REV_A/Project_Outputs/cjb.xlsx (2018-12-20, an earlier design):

Comment | Description | Designator | Footprint | LibRef | Quantity
Generic 0805 Capacitor | Generic 0805 Capacitor | C1, C2, C3, C4, C5, C6, C7, C8, C9, C10, C11, C12, C13, C14, C15, C16, C17, C20, C21, C22, C23, C24, C25, C26, C27, C28, C29, C30, C31, C32, C33, C34, C35, C36, C37 | 0805 | C_0805 | 35
Generic Electrolytic Capacitor | Generic PCAP_10x10 Can Aluminum Electrolytic Capacitor | C18, C19 | NIC-UUX2A470MNL1GS_M | C_can | 2
SMAJ58CA | Transient Voltage Suppressor, 6.40 to 231 V, 58 V Stand-off Voltage, Bi-Directional, -55 to 155 degC, 2-pin DO-214AC, Pb-Free, Tape and Reel | D1 | VISH-DO-214AC-2_M | SMAJ58CA | 1
BZT52C15T-7 | Zener Diode 15V 300mW ±6% Surface Mount SOD-523 | D2 | DIOD-SOD123-2_V | BZT52C15T | 1
ZX62D-B-5PA8 | Micro-USB Connector Meeting USB 2.0 Standard, -30 to 85 degC, 5-Pin SMD, RoHS, Tape and Reel | J1 | HIRO-ZX62D-B-5PA8_V | Micro_USB | 1
MI0805K601R-10 | Chip Bead for Power Filtering, 1500 mA, 600 Ohm, -40 to 125 degC, 0805 (2012 Metric), RoHS, Tape and Reel | L1 | LIRD-MI0805K601R-10-2_V | MI0805K | 1
Header 3 | Header, 3-Pin | P1, P6, P14 | HDR1X3 | Header 3 | 3
Header 6 | Header, 6-Pin | P2, P4 | HDR1X6 | Header 6 | 2
Header 4 | Header, 4-Pin | P3 | HDR1X4 | Header 4 | 1
Header 9 | Header, 9-Pin | P5 | HDR1X9 | Header 9 | 1
Header 8 | Header, 8-Pin | P7 | HDR1X8 | Header 8 | 1
Header 2 | Header, 2-Pin | P8, P10, P11, P12, P13 | HDR1X2 | Header 2 | 5
Header 5 | Header, 5-Pin | P15, P16 | HDR1X5 | Header 5 | 2
SI7288DP-T1-GE3 | Dual N-Channel (D-S) MOSFET, 40 V, 20 A, -55 to 150 degC, 8-Pin POWERPAKSO-8, RoHS, Tape and Reel | Q1 | VISH-POWERPAKSO-8_A_V | SI7288DP | 1
SQD50N10-8M9L_GE3 | N-Channel 100V 50A (Tc) 136W (Tc) Surface Mount TO-252 | Q2 | TO-252AA | SQD50N10 | 1
Generic 0603 Resistor | Generic 0603 Resistor | R1, R2, R3, R4, R5, R6, R7, R8, R9, R10, R11, R12, R13, R14, R15, R16, R17, R18, R19, R20, R21, R22, R23, R24, R25, R26, R27, R28, R29, R30, R31, R32, R33, R34, R35 | 0603 | R_0603 | 35
5001 | Test Point, Black, 1-Pin THD, RoHS, Bulk | TP1, TP2, TP3, TP4, TP5, TP6, TP7, TP8, TP9, TP10, TP11, TP12, TP13, TP14, TP15, TP16, TP17, TP18, TP19, TP20, TP21, TP22, TP23, TP24, TP25, TP26, TP27, TP28, TP29, TP30, TP31, TP32, TP33, TP34 | KSTN-5001 | TP5001 | 34
CJ125 | 5V 2Mbaud SMT Lambda Probe Interface IC - SOIC-24 | U1 | SOIC-24 | CJ125 | 1
STM32L475RCT3 | Ultra-Low-Power ARM Cortex-M4 32-bit MCU+FPU, 256 KB Flash, 128 KB Internal RAM, 51 I/Os, 64-Pin LQFP, -40 to 125 degC, Tray | U2 | STM-LQFP64_L | STM32L475RCT3 | 1
TPS7A6150QKVURQ1 | Single Output Automotive LDO, 300 mA, Fixed 5 V Output, 4 to 40 V Input, with Ultra-Low IQ, 5-pin PFM (KVU), -40 to 125 degC, Green (RoHS & no Sb/Br) | U3 | KVU0005A_M | TPS7A6150-Q1 | 1
LT4367HMS | 100V Overvoltage, Undervoltage and Reverse Supply Protection Controller | U4 | MSOP8_M | LT4367 | 1
TLV71333PDBVR | REG LINEAR 3.3V 150MA SOT23-5 | U5 | DBV5-M | TLV71333PDBVR | 1
TXB0104PWR | 4-Bit Bidirectional Voltage-Level Translator with Automatic Direction Sensing and +/- 15-kV ESD Protection, -40 to 85 degC, 14-Pin TSSOP (PW), Green (RoHS & Sb/Br), Tape and Reel | U6 | PW0014A_M | TXB0104 | 1
MCP6L02T-E/MS | 1 MHz, 85 Î¼A Dual Op Amp, 8-Pin MSOP, Extended Temperature Range, Tape and Reel | U7, U8 | MSOP8_M | MCP6L02 | 2
LMV341MG/NOPB | Single with Shutdown/Dual/Quad General Purpose, 2.7V, Rail-to-Rail Output, 125°C, Operational Amplifiers, 6-pin SC-70, Pb-Free | U9 | DCK0006A_M | LMV341 | 1
UCC27519DBVT | Low-Side Gate Driver IC Non-Inverting SOT-23-5 | U10 | DBV5-M | UCC27519 | 1

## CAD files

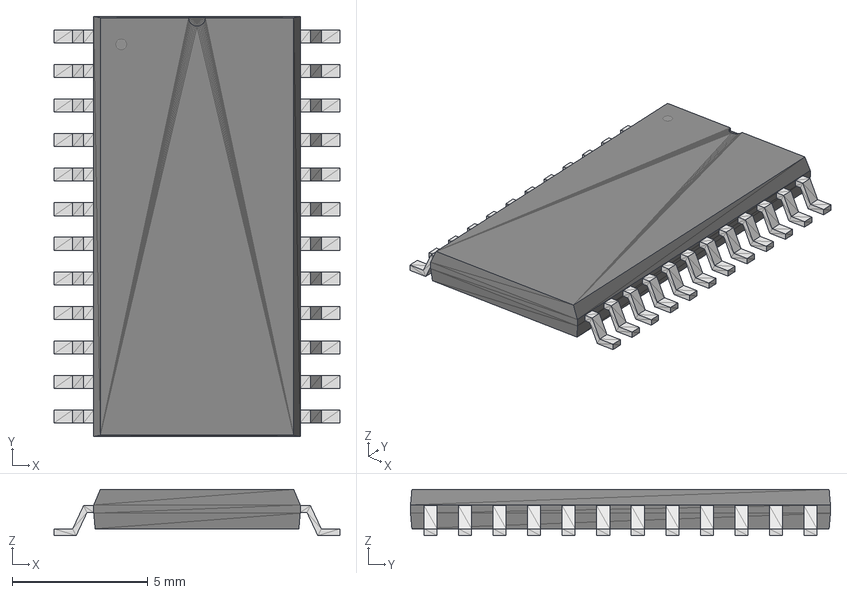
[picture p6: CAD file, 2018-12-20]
pcb/INT/R_24.stp
10.5 x 15.4 x 1.70 mm

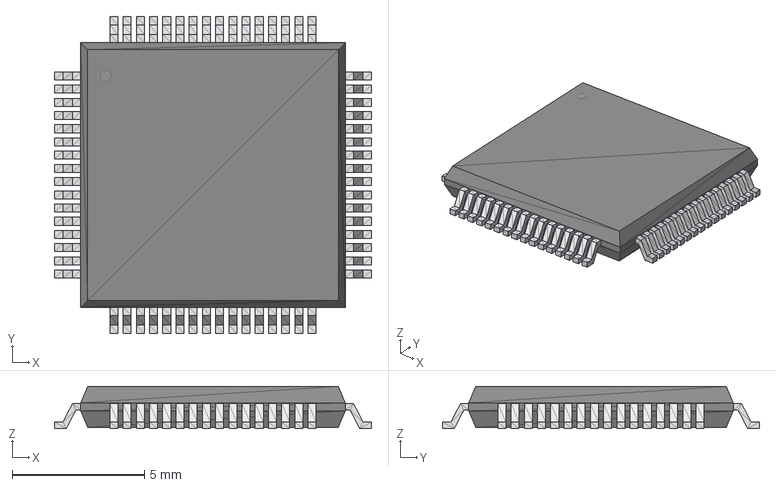
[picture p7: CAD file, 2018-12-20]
pcb/INT/LQFP64-10x10mm.stp
12.0 x 12.0 x 1.60 mm

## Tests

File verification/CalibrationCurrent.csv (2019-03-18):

#Digilent WaveForms Oscilloscope Acquisition
#Device Name: Discovery2
#Serial Number: SN:210321A36376
#Date Time: 2019-03-14 16:04:16.854
#Sample rate: 800000Hz
#Samples: 8192
#Trigger: Source: Channel 1 Type: Edge Condition: Rising Level: 2.95 V Hyst.: Auto HoldOff: 0 s
#Channel 1: Range: 500 mV/div Offset: -500 mV
#Channel 2: Range: 500 mV/div Offset: -500 mV
#Math 1: Function: (C1-C2)/301
Time (s) | Channel 1 (V) | Channel 2 (V) | Math 1 (A)
-0.00512 | -0.0270637 | -0.00127197 | -8.56867e-05
-0.00511875 | -0.0273949 | -0.00160749 | -8.56723e-05
-0.0051175 | -0.0273949 | -0.001943 | -8.45577e-05
-0.00511625 | -0.0270637 | -0.001943 | -8.34574e-05
-0.005115 | -0.0267325 | -0.00160749 | -8.34717e-05
-0.00511375 | -0.0270637 | -0.00160749 | -8.4572e-05
-0.0051125 | -0.0267325 | -0.00160749 | -8.34717e-05
-0.00511125 | -0.0267325 | -0.00127197 | -8.45864e-05
-0.00511 | -0.0270637 | -0.000936452 | -8.68014e-05
-0.00510875 | -0.0264013 | -0.000936452 | -8.46008e-05
-0.0051075 | -0.0267325 | -0.00127197 | -8.45864e-05
-0.00510625 | -0.0267325 | -0.00127197 | -8.45864e-05
-0.005105 | -0.0267325 | -0.000936452 | -8.57011e-05
-0.00510375 | -0.0264013 | -0.000936452 | -8.46008e-05
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

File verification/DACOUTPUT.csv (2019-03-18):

#Digilent WaveForms Oscilloscope Acquisition
#Device Name: Discovery2
#Serial Number: SN:210321A36376
#Date Time: 2019-03-14 16:46:10.204
#Sample rate: 800Hz
#Samples: 8192
#Trigger: Source: Channel 1 Type: Edge Condition: Rising Level: 0 V Hyst.: Auto HoldOff: 0 s
#Channel 1: Range: 1 V/div Offset: -2 V
#Channel 2: Range: 1 V/div Offset: -2 V
#Our λ: Function: C1/5*(1.36-0.65)+0.65
#Their λ: Function: C2/5*(1.36-0.68)+0.68
#Difference λ: Function: M2 -M1
Time (s) | Channel 1 (V) | Channel 2 (V) | Our λ (λ) | Their λ (λ) | Difference λ (λ)
-5.1175 | 2.17788 | 2.49592 | 0.95926 | 1.01945 | 0.0601859
-5.11625 | 2.17788 | 2.49592 | 0.95926 | 1.01945 | 0.0601859
-5.115 | 2.17788 | 2.49224 | 0.95926 | 1.01894 | 0.0596844
-5.11375 | 2.18516 | 2.49592 | 0.960292 | 1.01945 | 0.0591531
-5.1125 | 2.18516 | 2.49592 | 0.960292 | 1.01945 | 0.0591531
-5.11125 | 2.18516 | 2.49592 | 0.960292 | 1.01945 | 0.0591531
-5.11 | 2.18516 | 2.49592 | 0.960292 | 1.01945 | 0.0591531
-5.10875 | 2.18516 | 2.49592 | 0.960292 | 1.01945 | 0.0591531
-5.1075 | 2.18516 | 2.49592 | 0.960292 | 1.01945 | 0.0591531
-5.10625 | 2.18516 | 2.49224 | 0.960292 | 1.01894 | 0.0586517
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

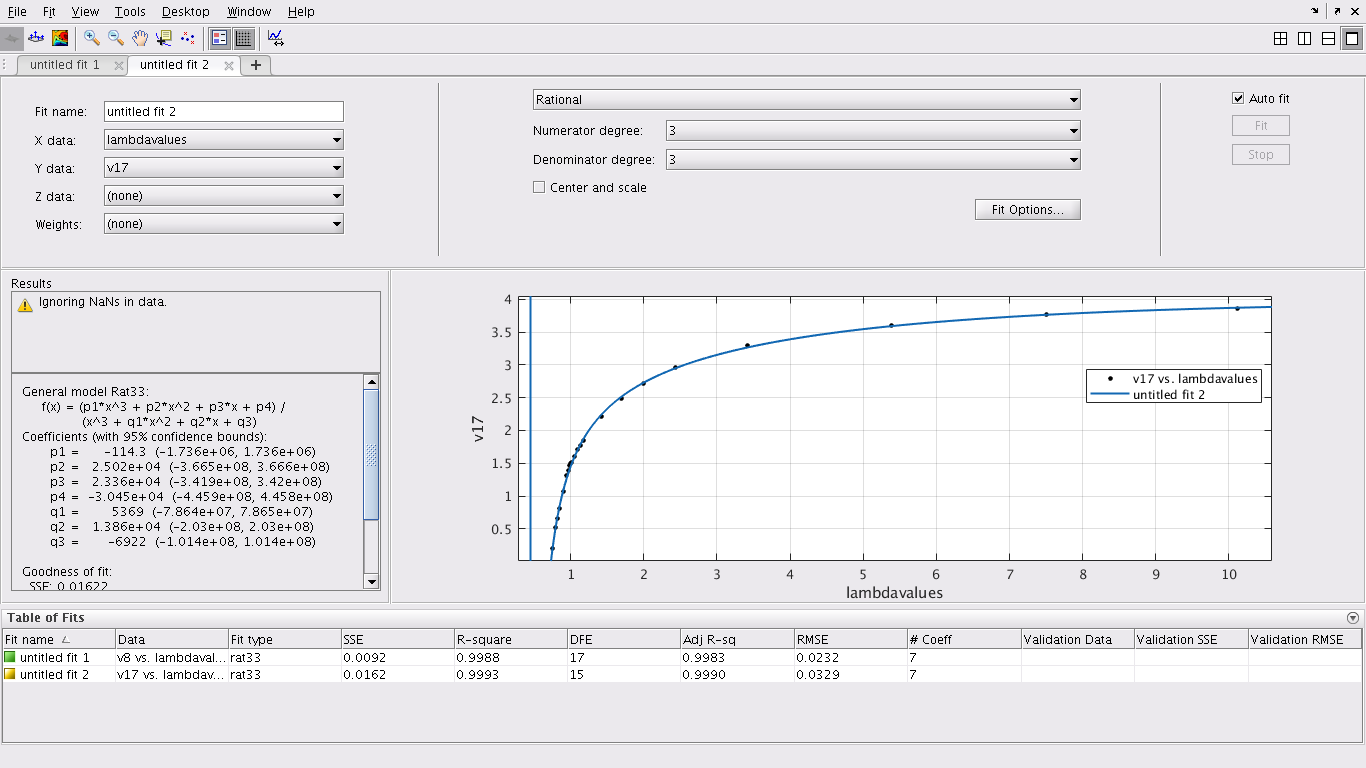
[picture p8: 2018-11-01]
verification/V17_curvefit.png

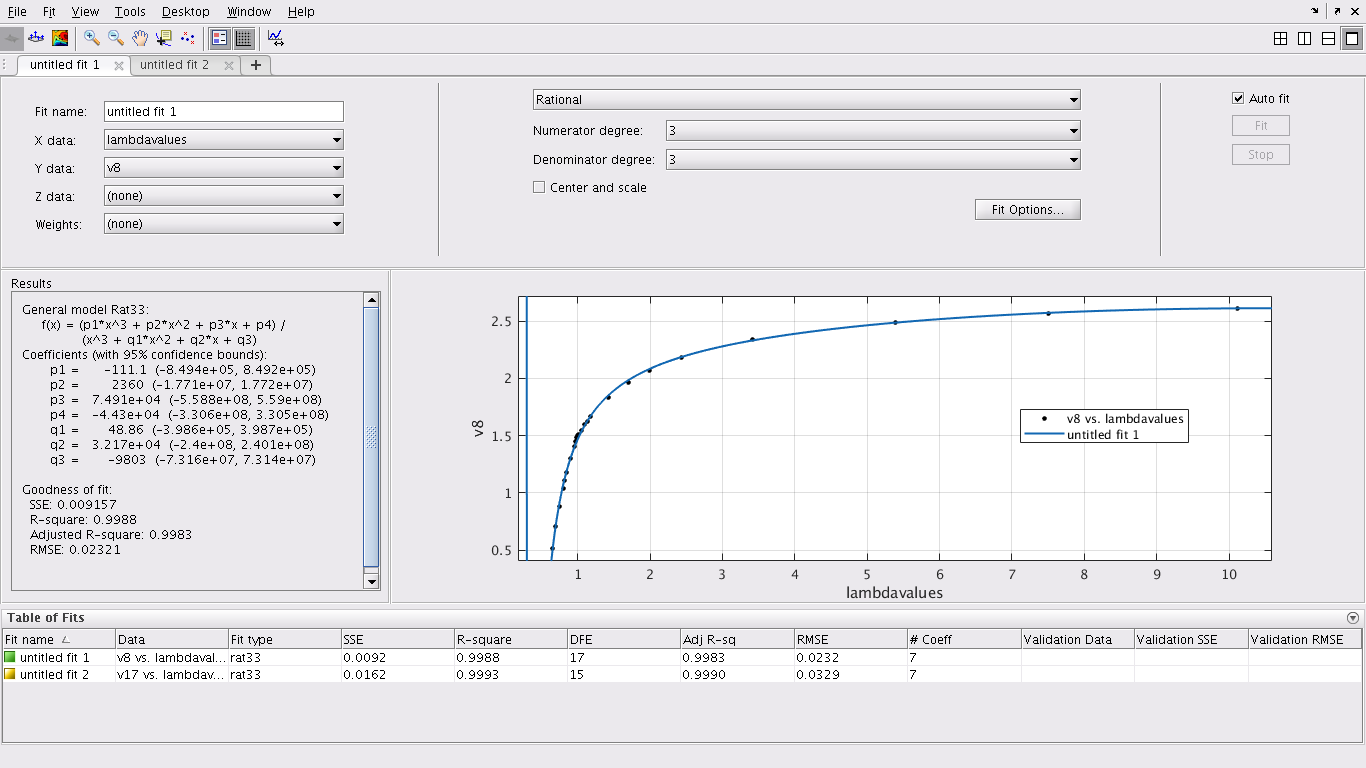
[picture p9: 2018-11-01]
verification/V8_curvefit.png

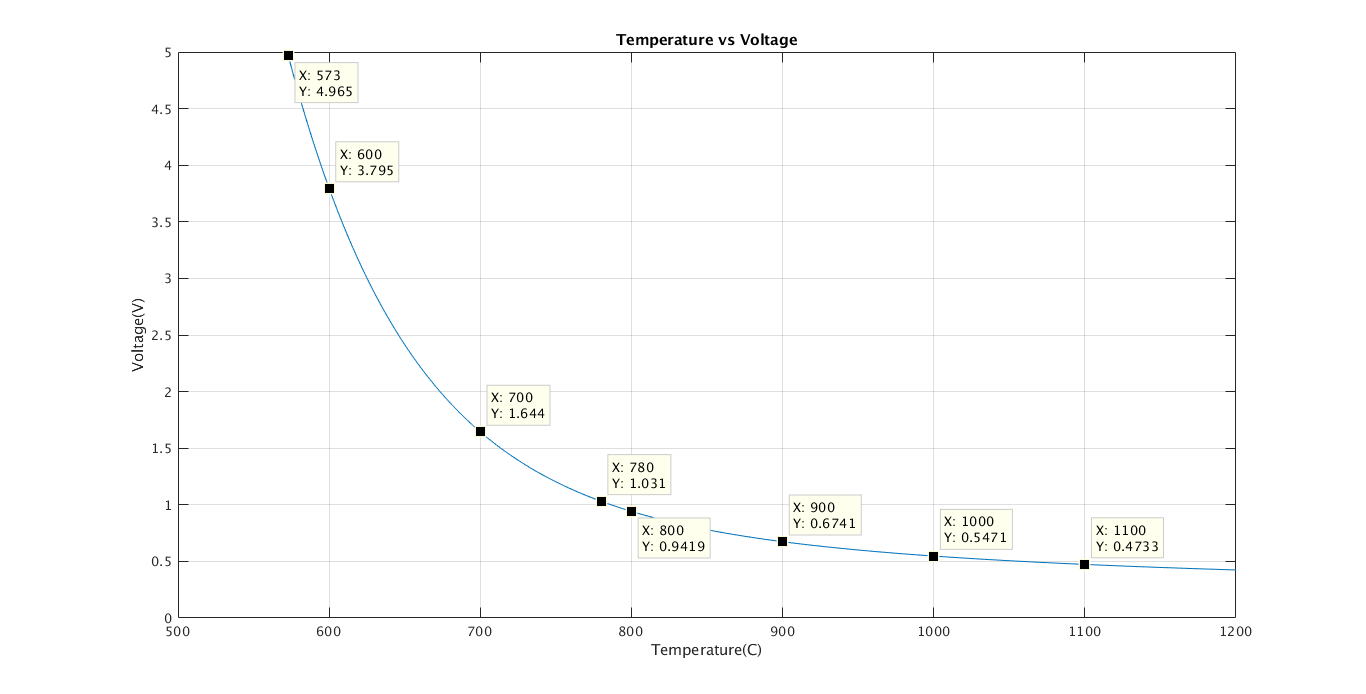
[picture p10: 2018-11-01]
verification/UR.png

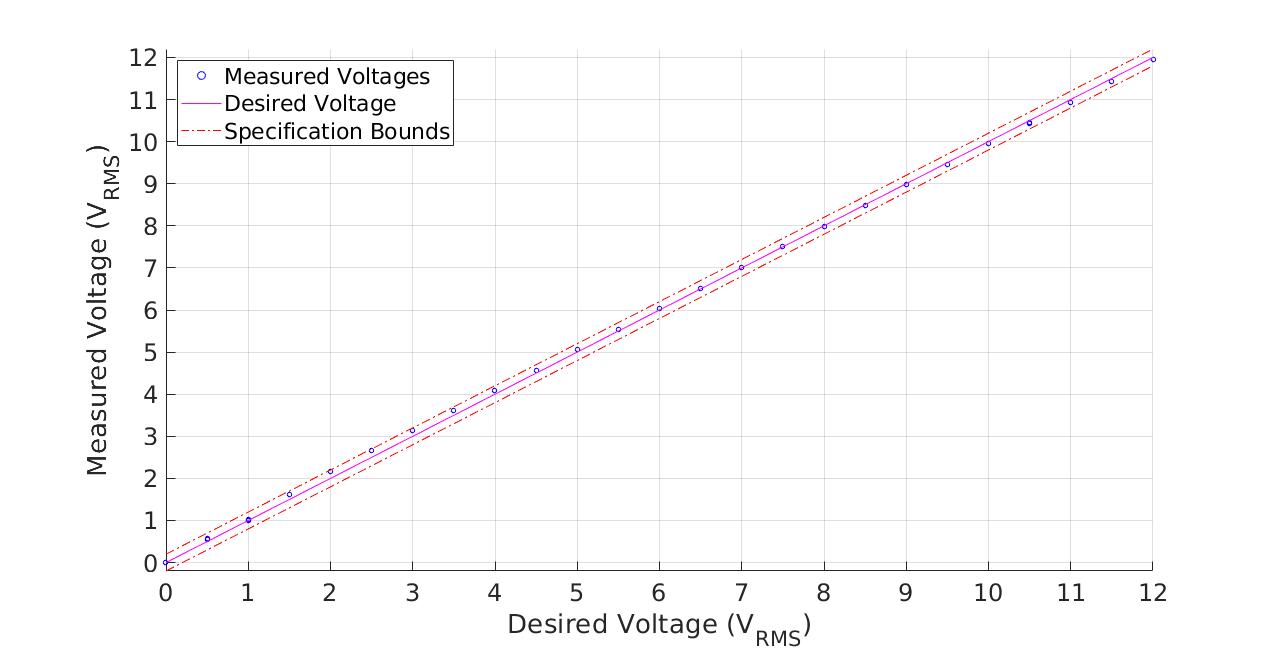
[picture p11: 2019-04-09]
verification/PWMSpec.jpg

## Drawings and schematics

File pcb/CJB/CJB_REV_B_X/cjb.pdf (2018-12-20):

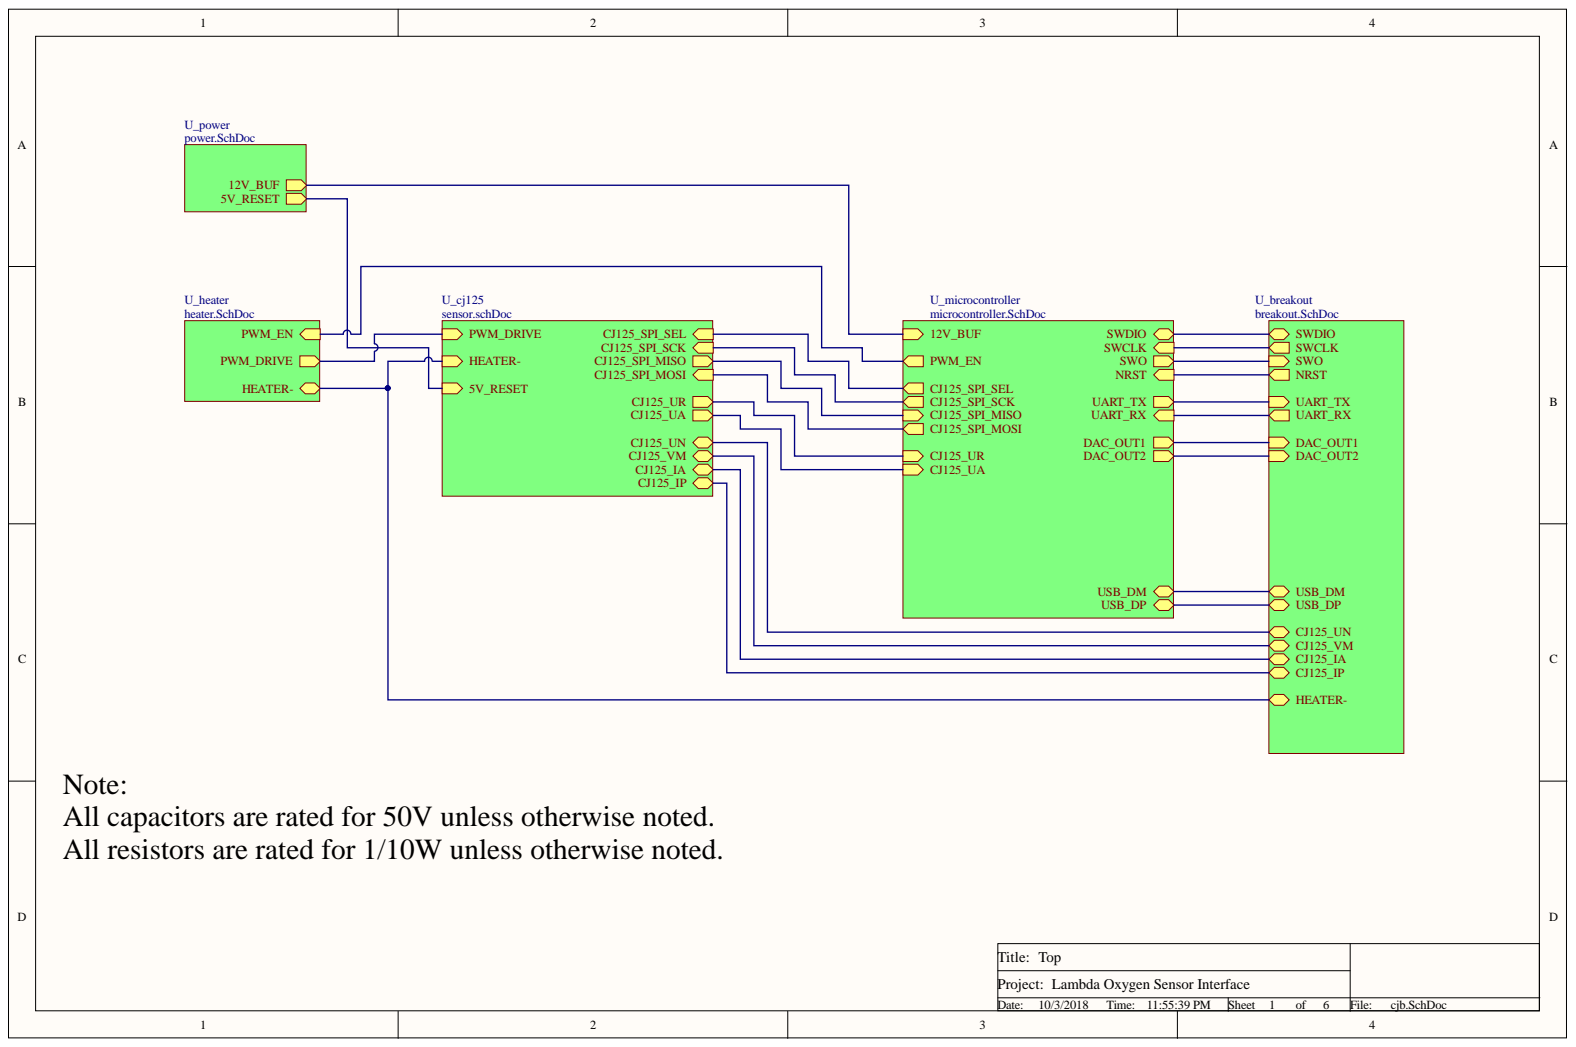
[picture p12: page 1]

CJ125_SPI_SCK HEATER-CJ125_SPI_MISO

CJ125_SPI_MOSI 5V_RESET CJ125_UR CJ125_UA CJ125_UN CJ125_VM CJ125_IA CJ125_IP | | | NRST CJ125_SPI_SEL CJ125_SPI_SCK UART_TX CJ125_SPI_MISO UART_RX CJ125_SPI_MOSI DAC_OUT1

CJ125_UR DAC_OUT2
CJ125_UA

USB_DM USB_DP

Note:
All capacitors are rated for 50V unless otherwise noted.
All resistors are rated for 1/10W unless otherwise noted.

Lambda Oxygen Sensor Interface

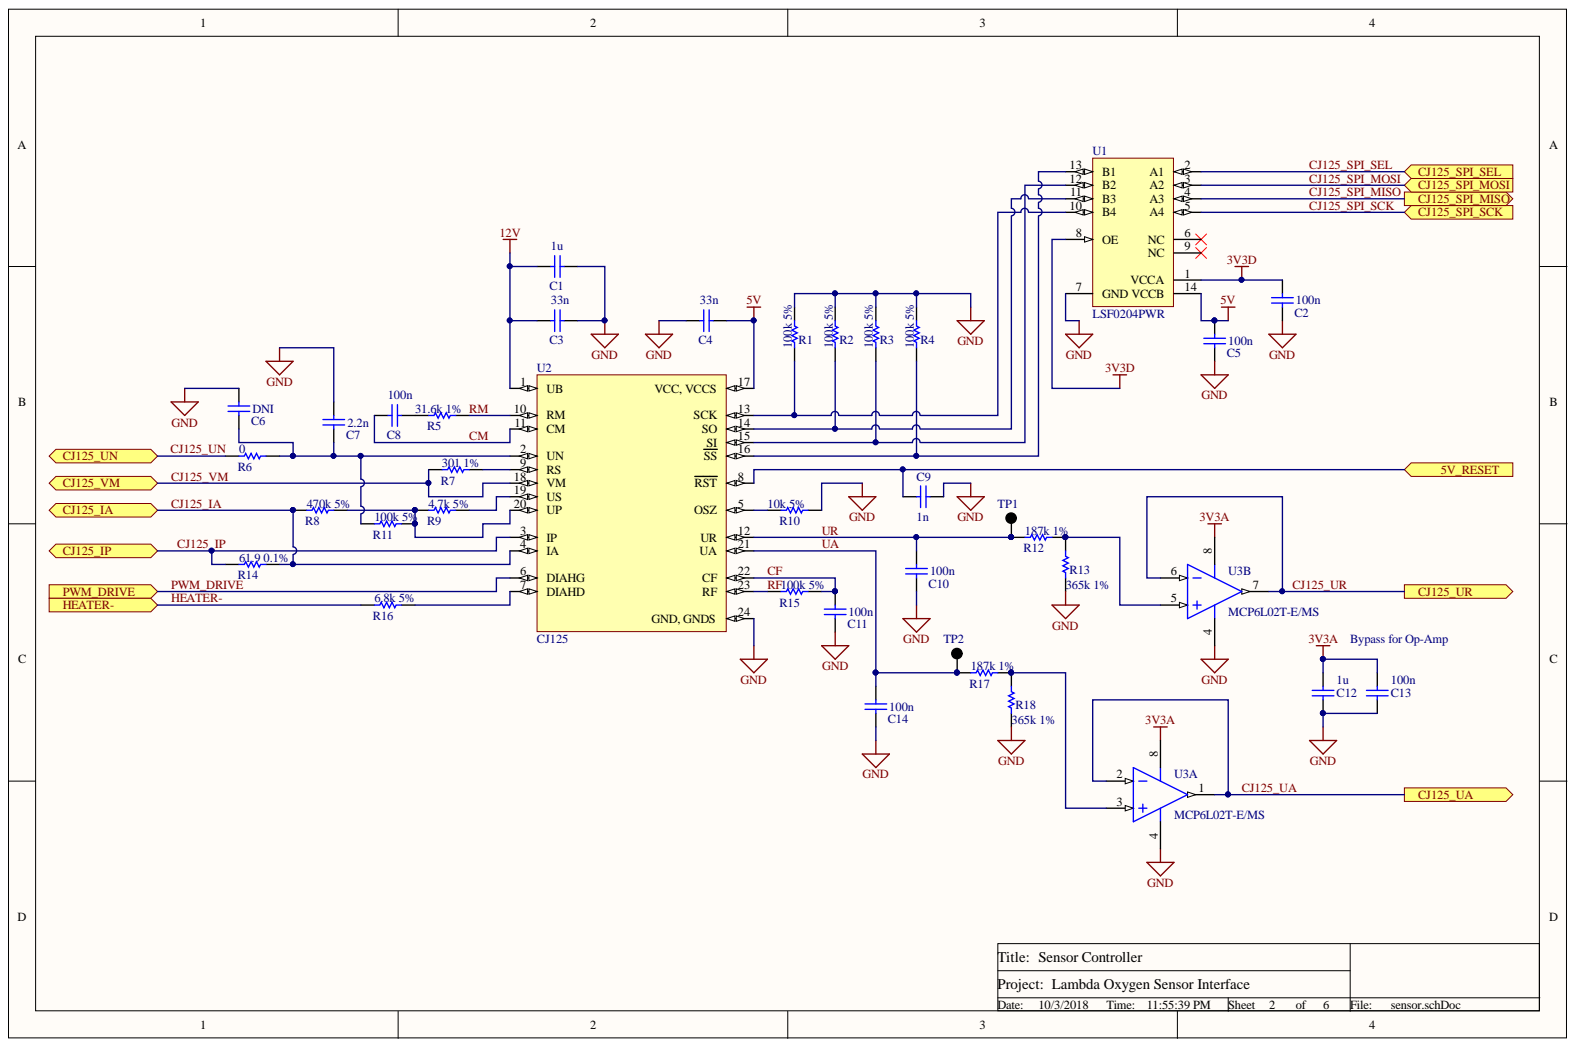
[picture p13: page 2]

Bypass for Op-Amp

Lambda Oxygen Sensor Interface

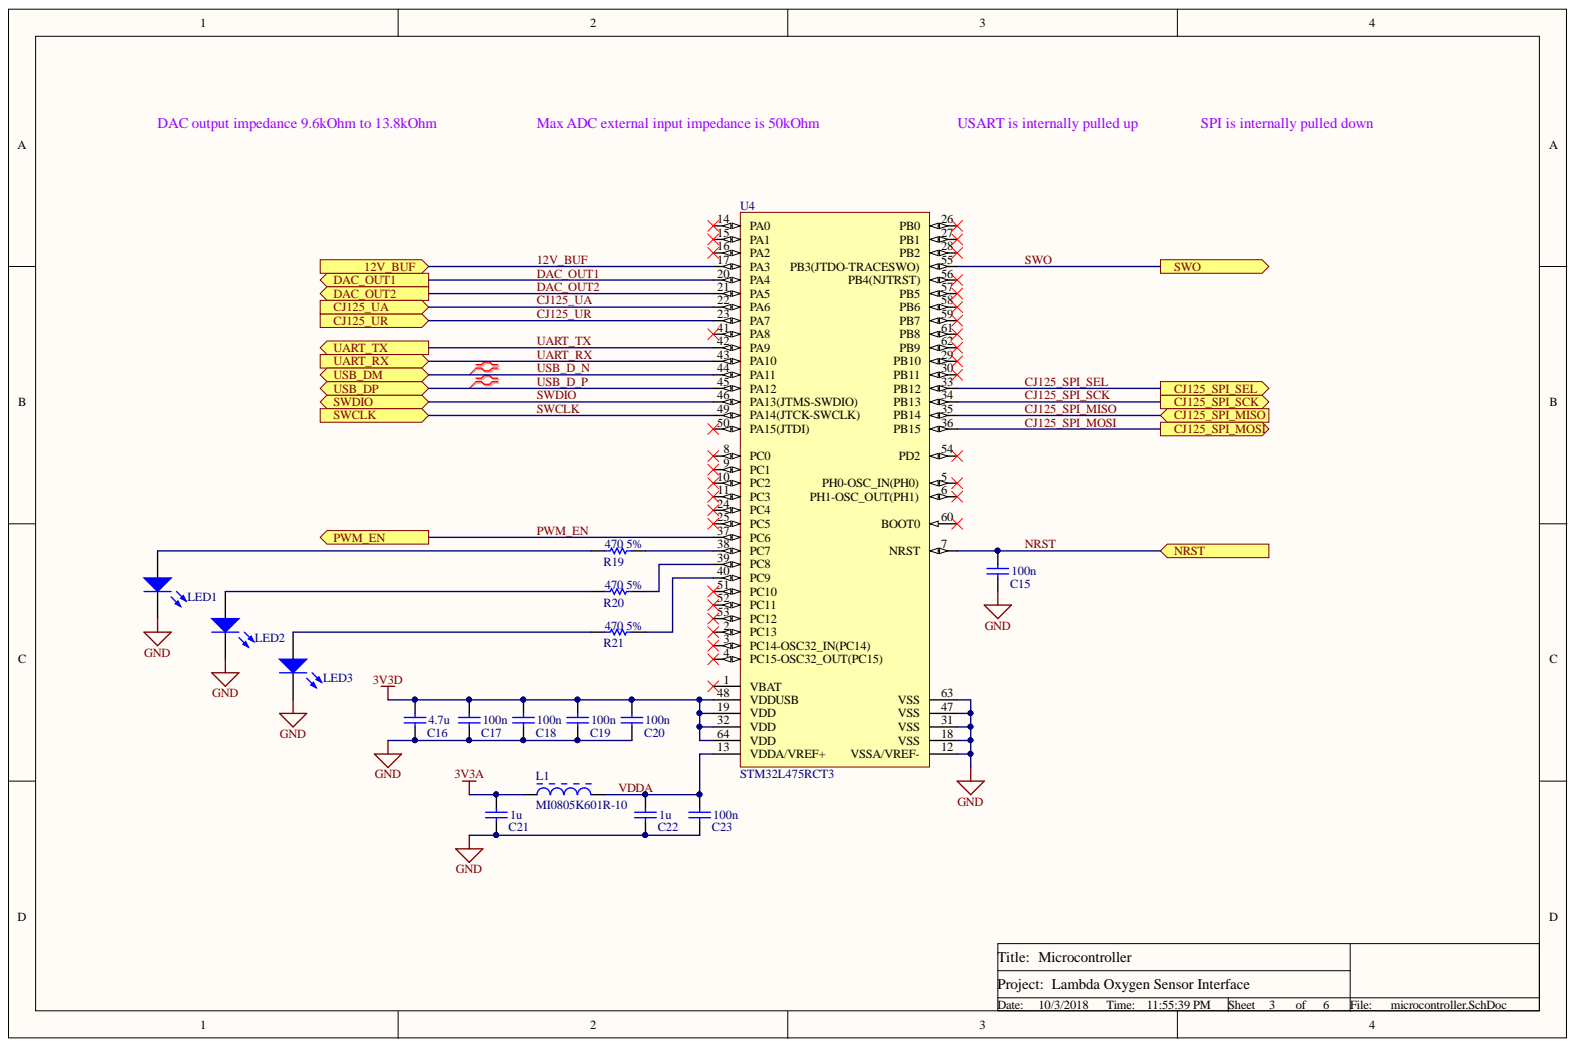
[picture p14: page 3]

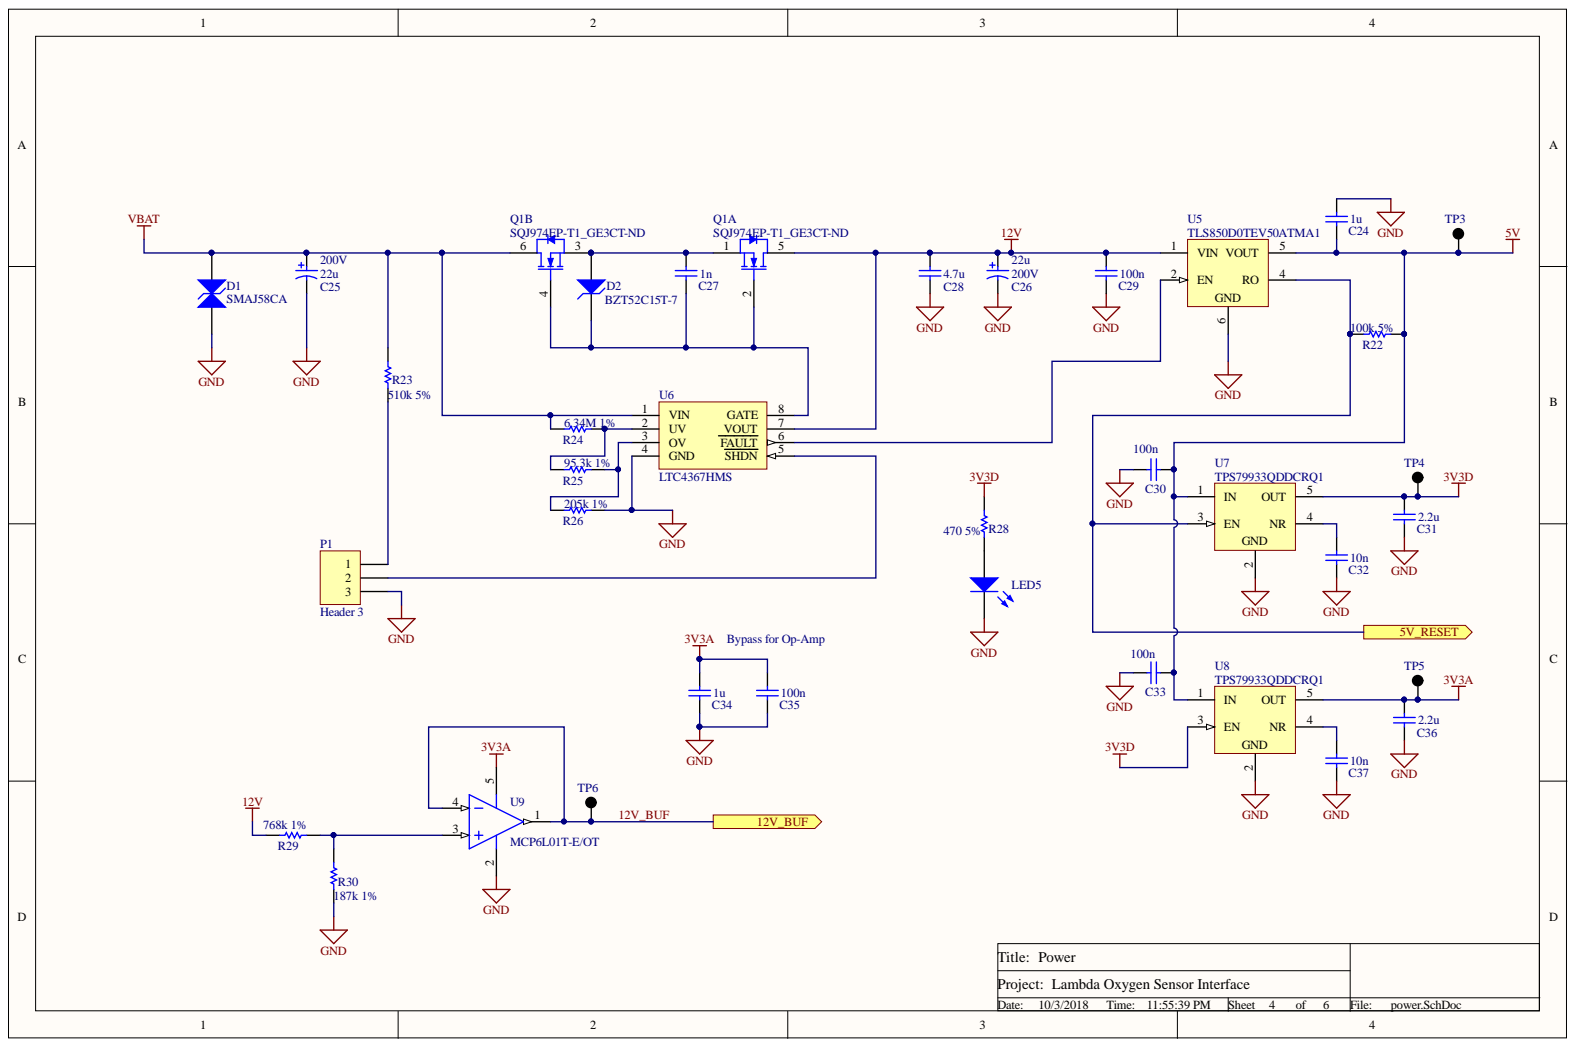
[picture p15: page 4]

4 | 5 | GN | U 7 TP S79933Q D D C R Q 1

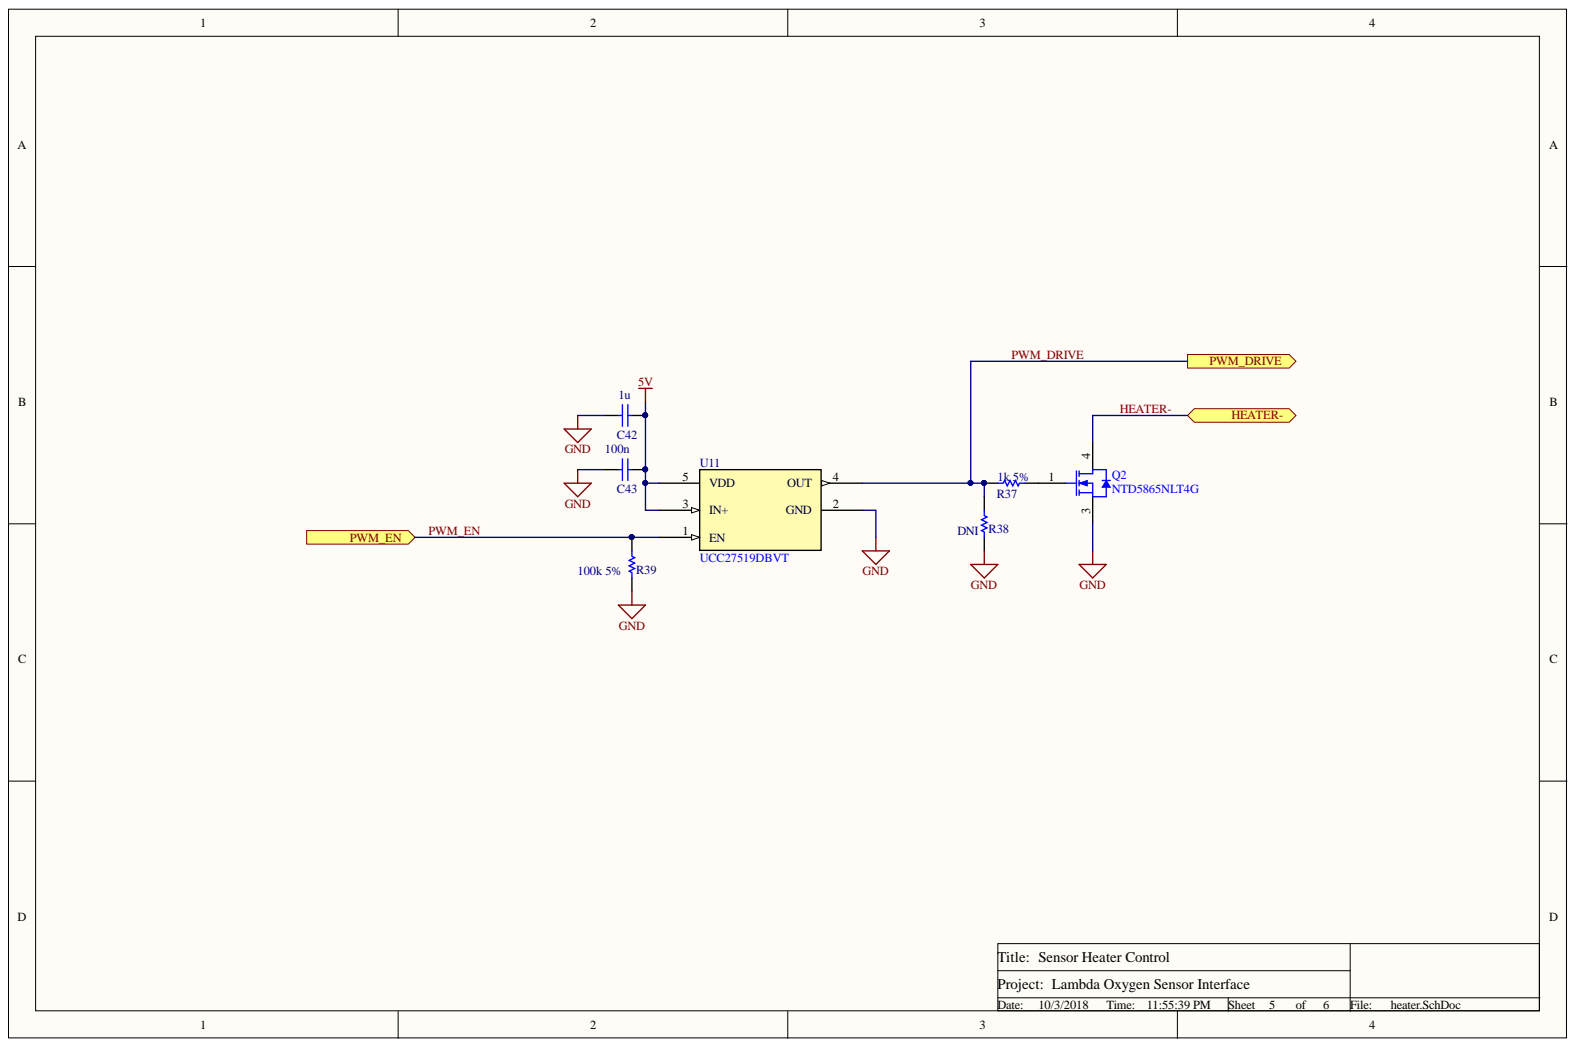
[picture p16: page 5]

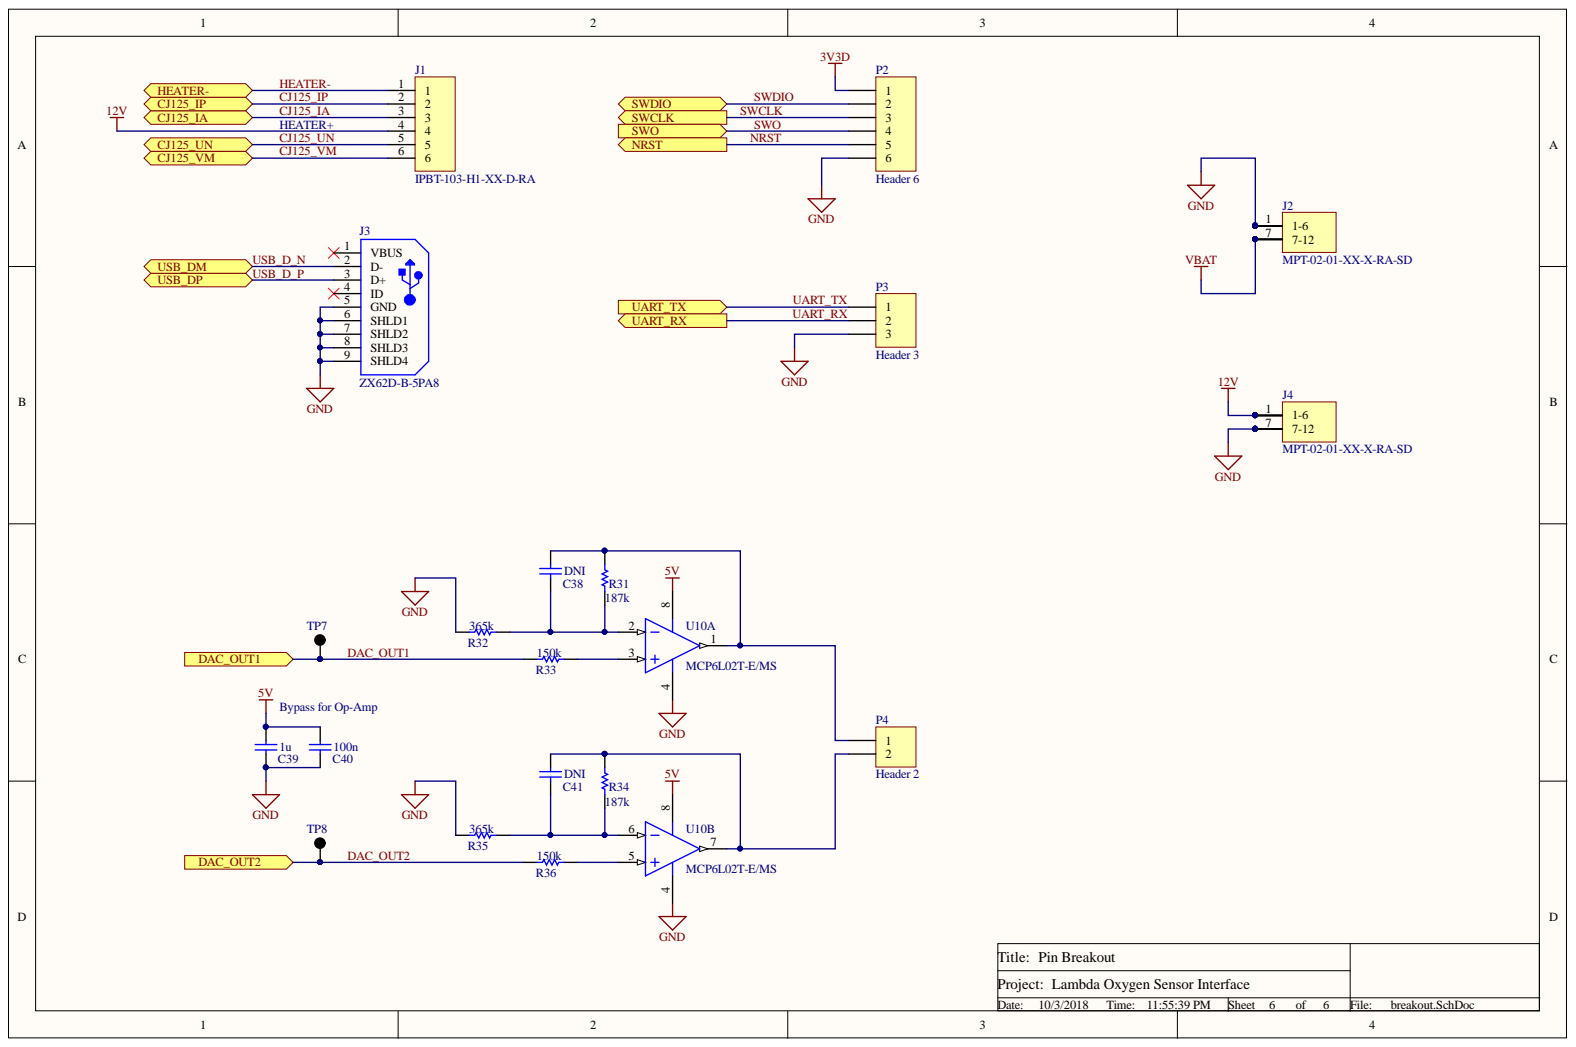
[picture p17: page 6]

MPT-02-01-XX-X-RA-SD

Bypass for Op-Amp

Lambda Oxygen Sensor Interface

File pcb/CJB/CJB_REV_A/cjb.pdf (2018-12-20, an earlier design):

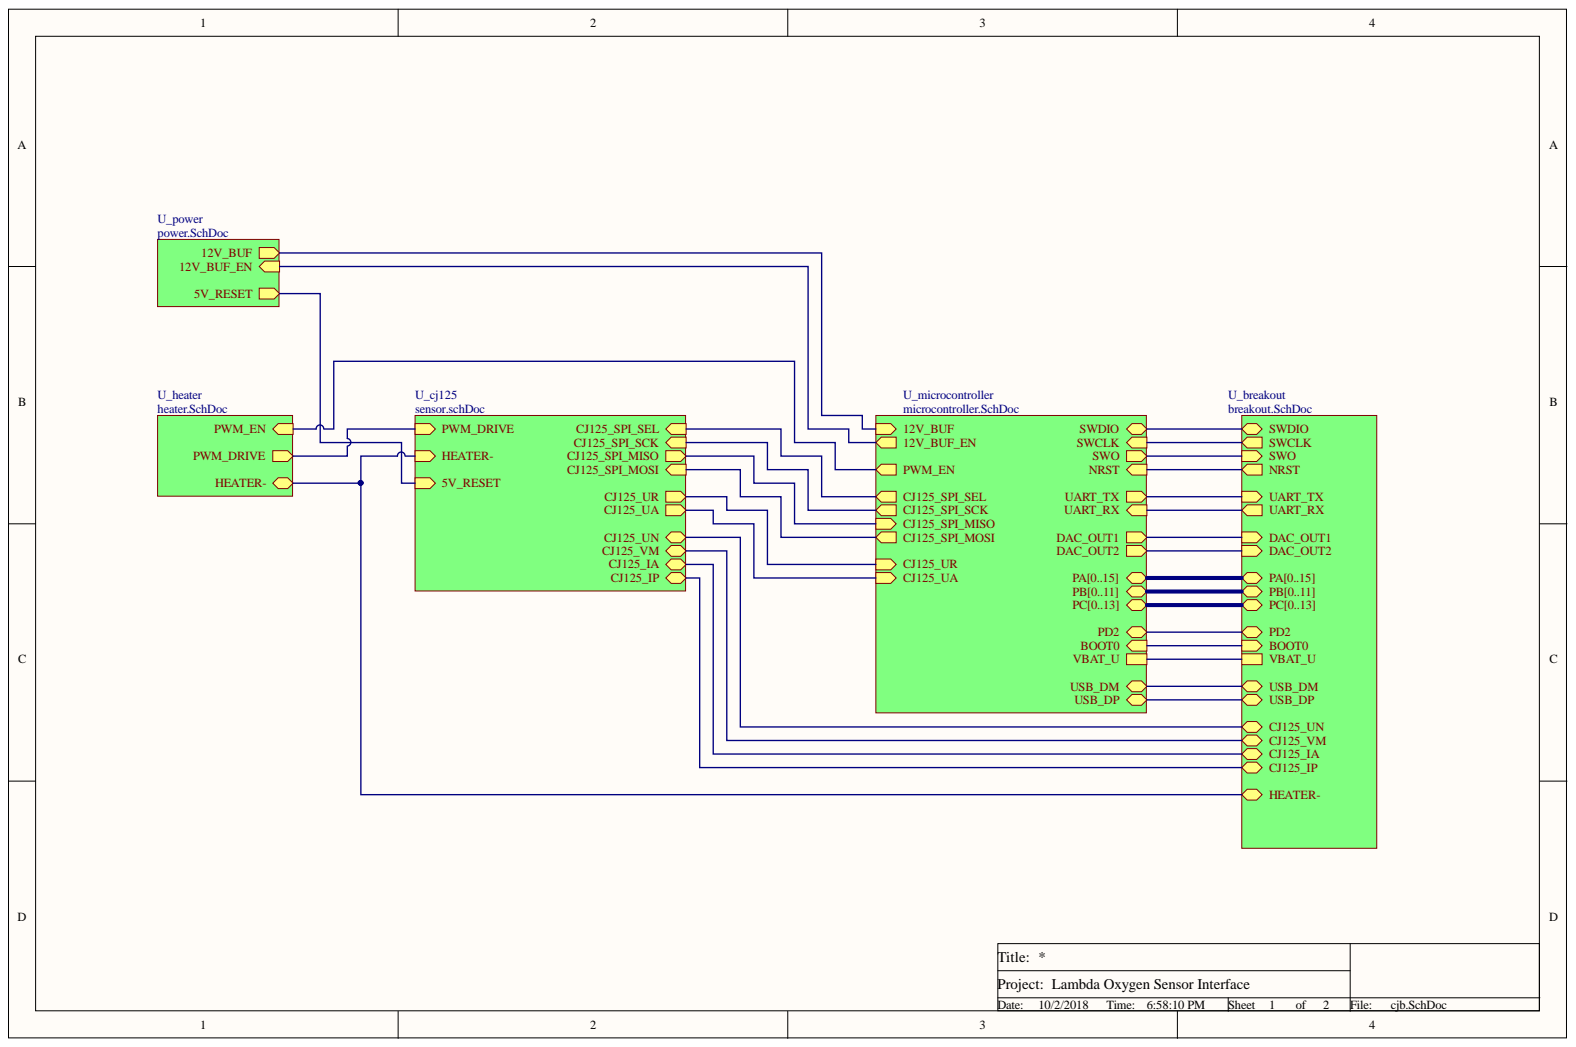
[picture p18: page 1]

CJ125_SPI_MOSI 5V_RESET CJ125_UR CJ125_UA CJ125_UN CJ125_VM CJ125_IA CJ125_IP | | PWM_EN NRST CJ125_SPI_SEL UART_TX CJ125_SPI_SCK UART_RX CJ125_SPI_MISO CJ125_SPI_MOSI DAC_OUT1

CJ125_UR
CJ125_UA PA[0..15] PB[0..11] PC[0..13] PD2 BOOT0 USB_DM USB_DP

DAC_OUT2

Lambda Oxygen Sensor Interface

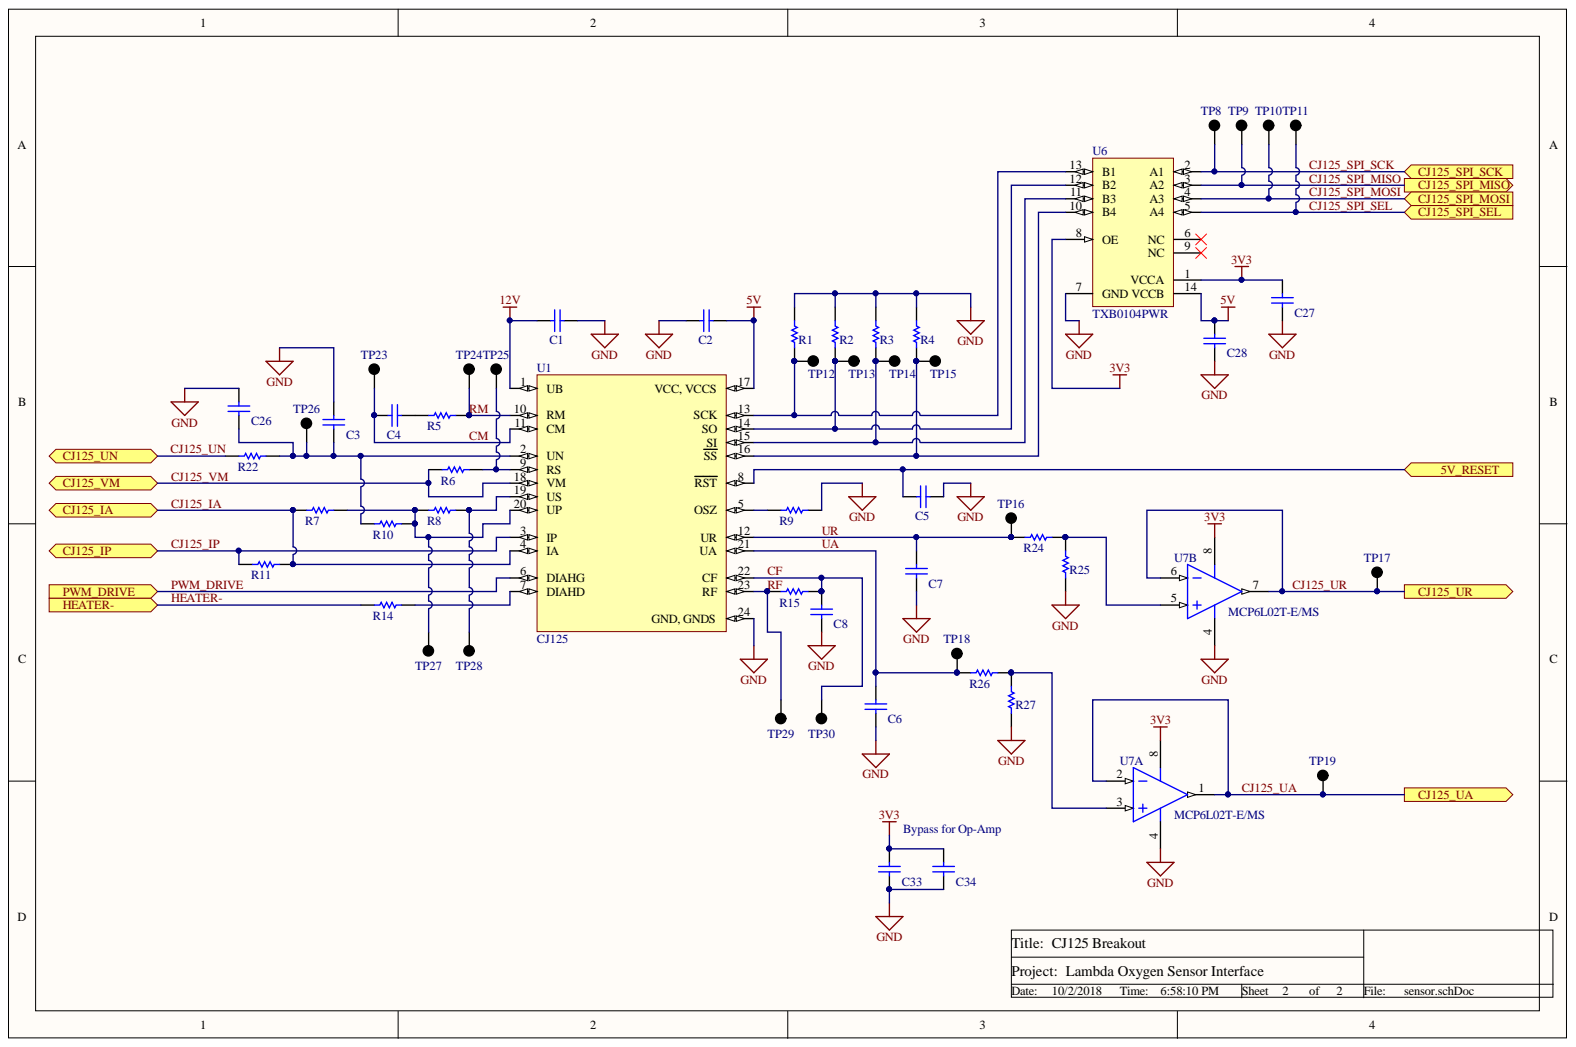
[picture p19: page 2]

Bypass for Op-Amp

Lambda Oxygen Sensor Interface

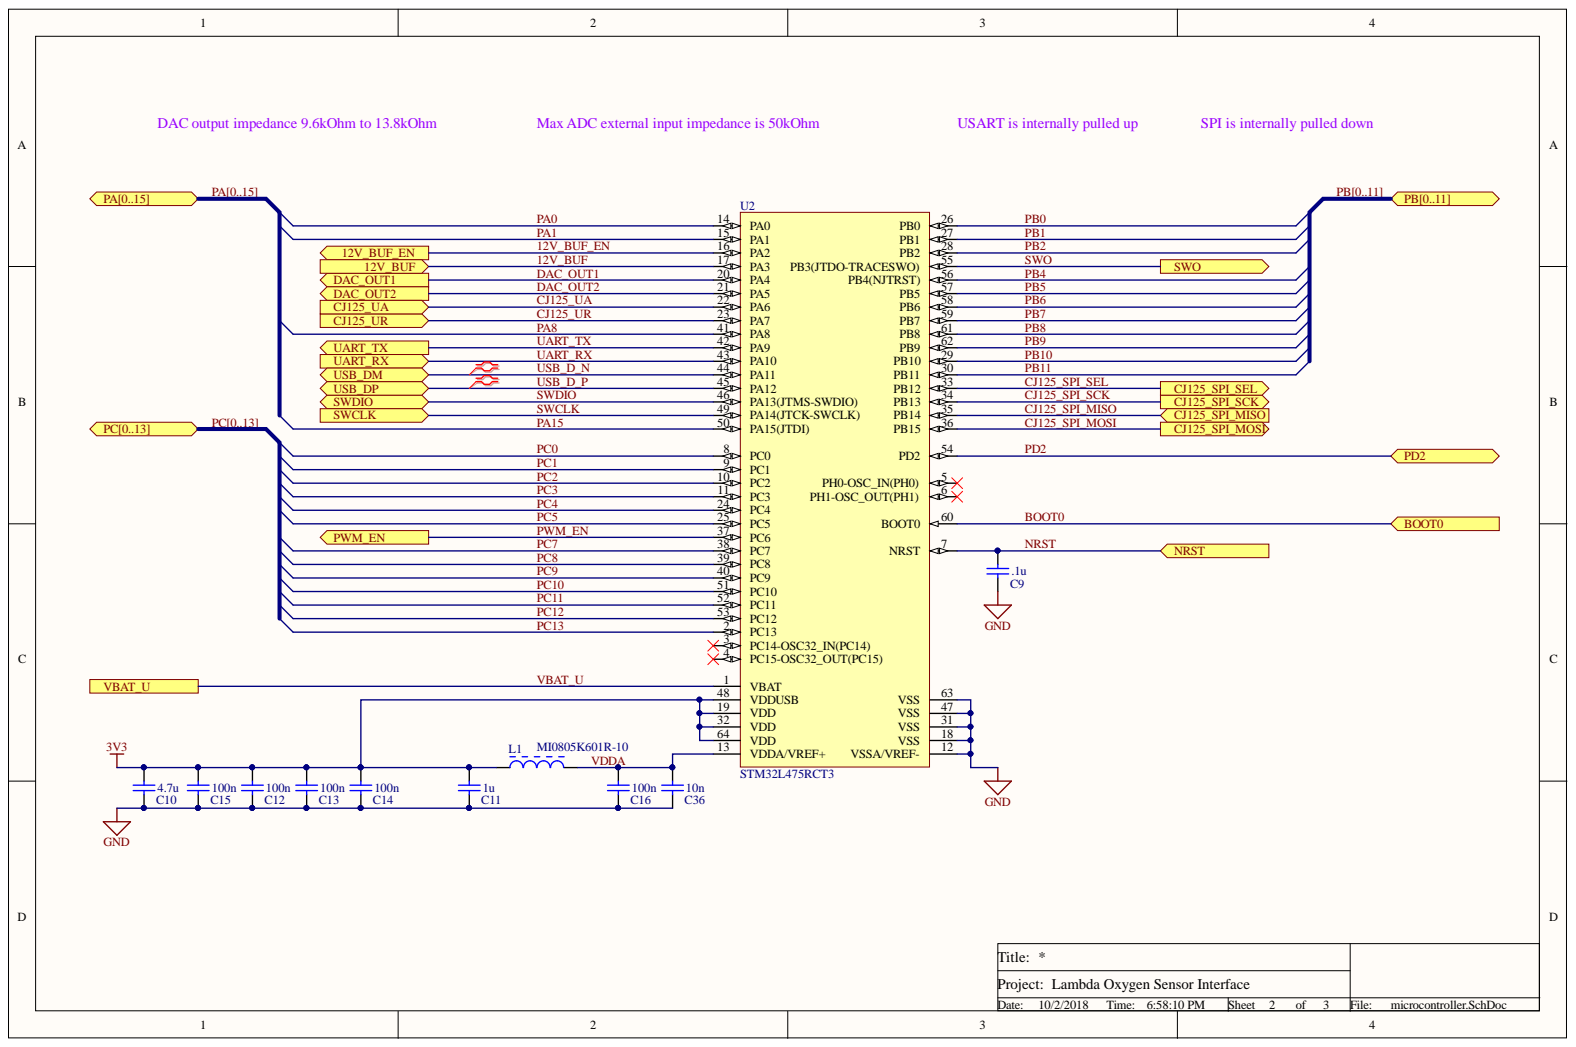
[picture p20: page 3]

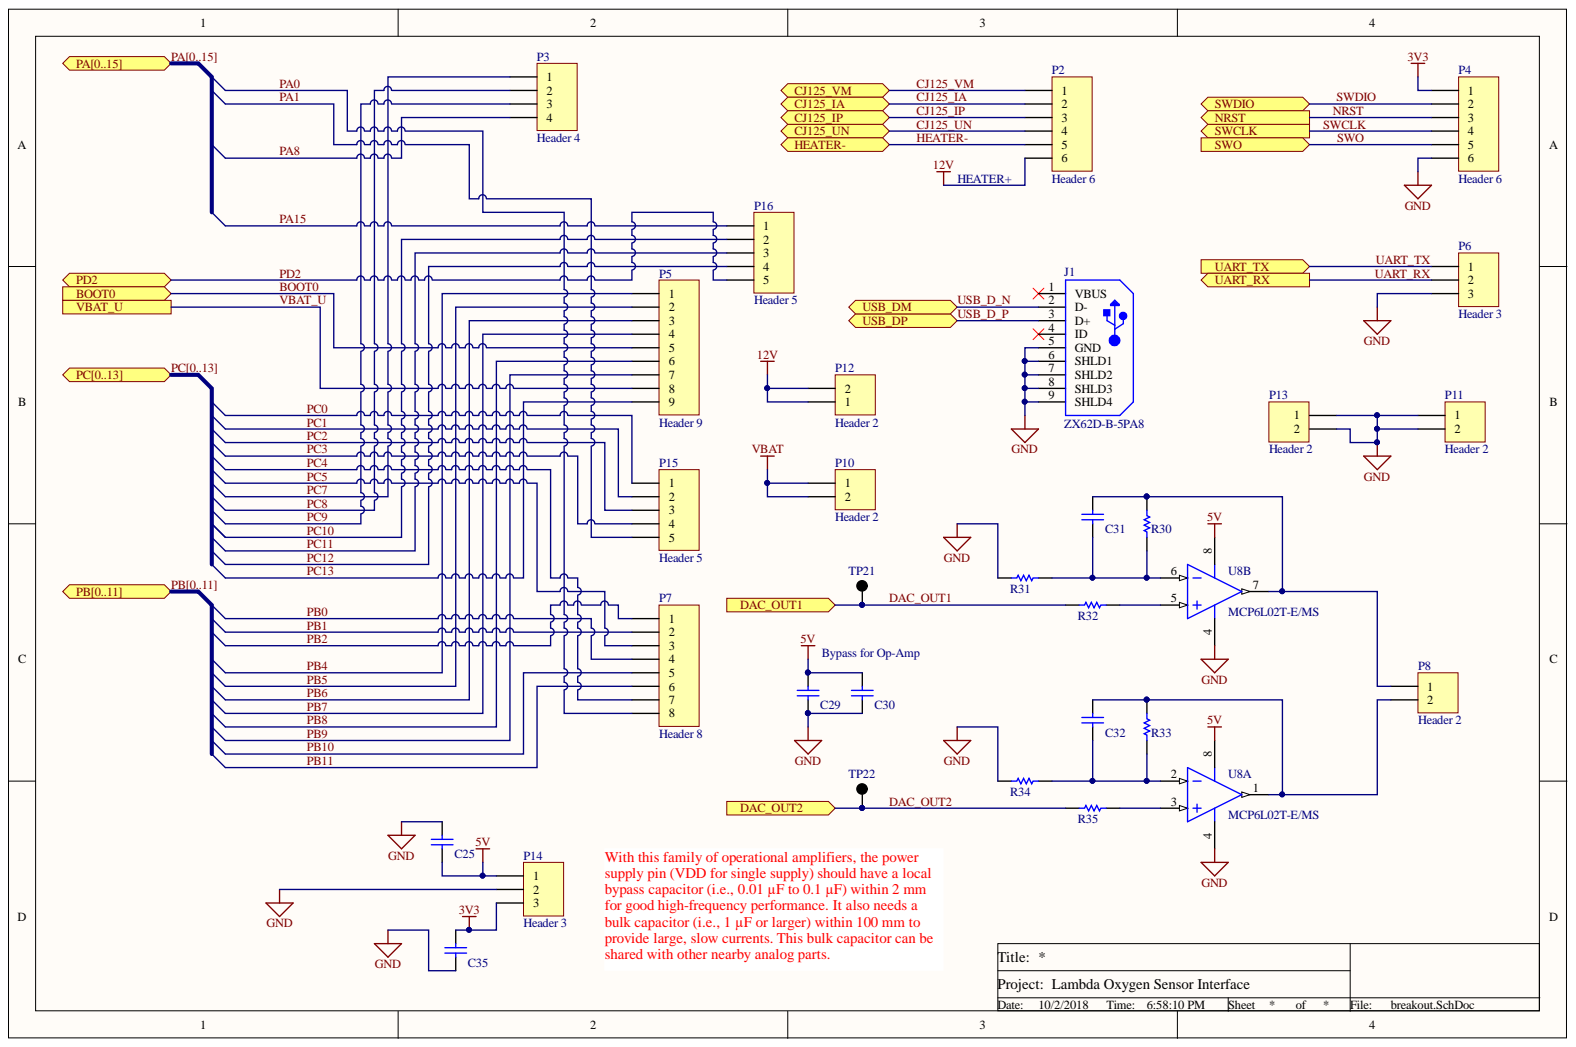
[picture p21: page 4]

Bypass for Op-Amp

With this family of operational amplifiers, the power
supply pin (VDD for single supply) should have a local
bypass capacitor (i.e., 0.01 µF to 0.1 µF) within 2 mm
for good high-frequency performance. It also needs a
bulk capacitor (i.e., 1 µF or larger) within 100 mm to
provide large, slow currents. This bulk capacitor can be
shared with other nearby analog parts.

Lambda Oxygen Sensor Interface

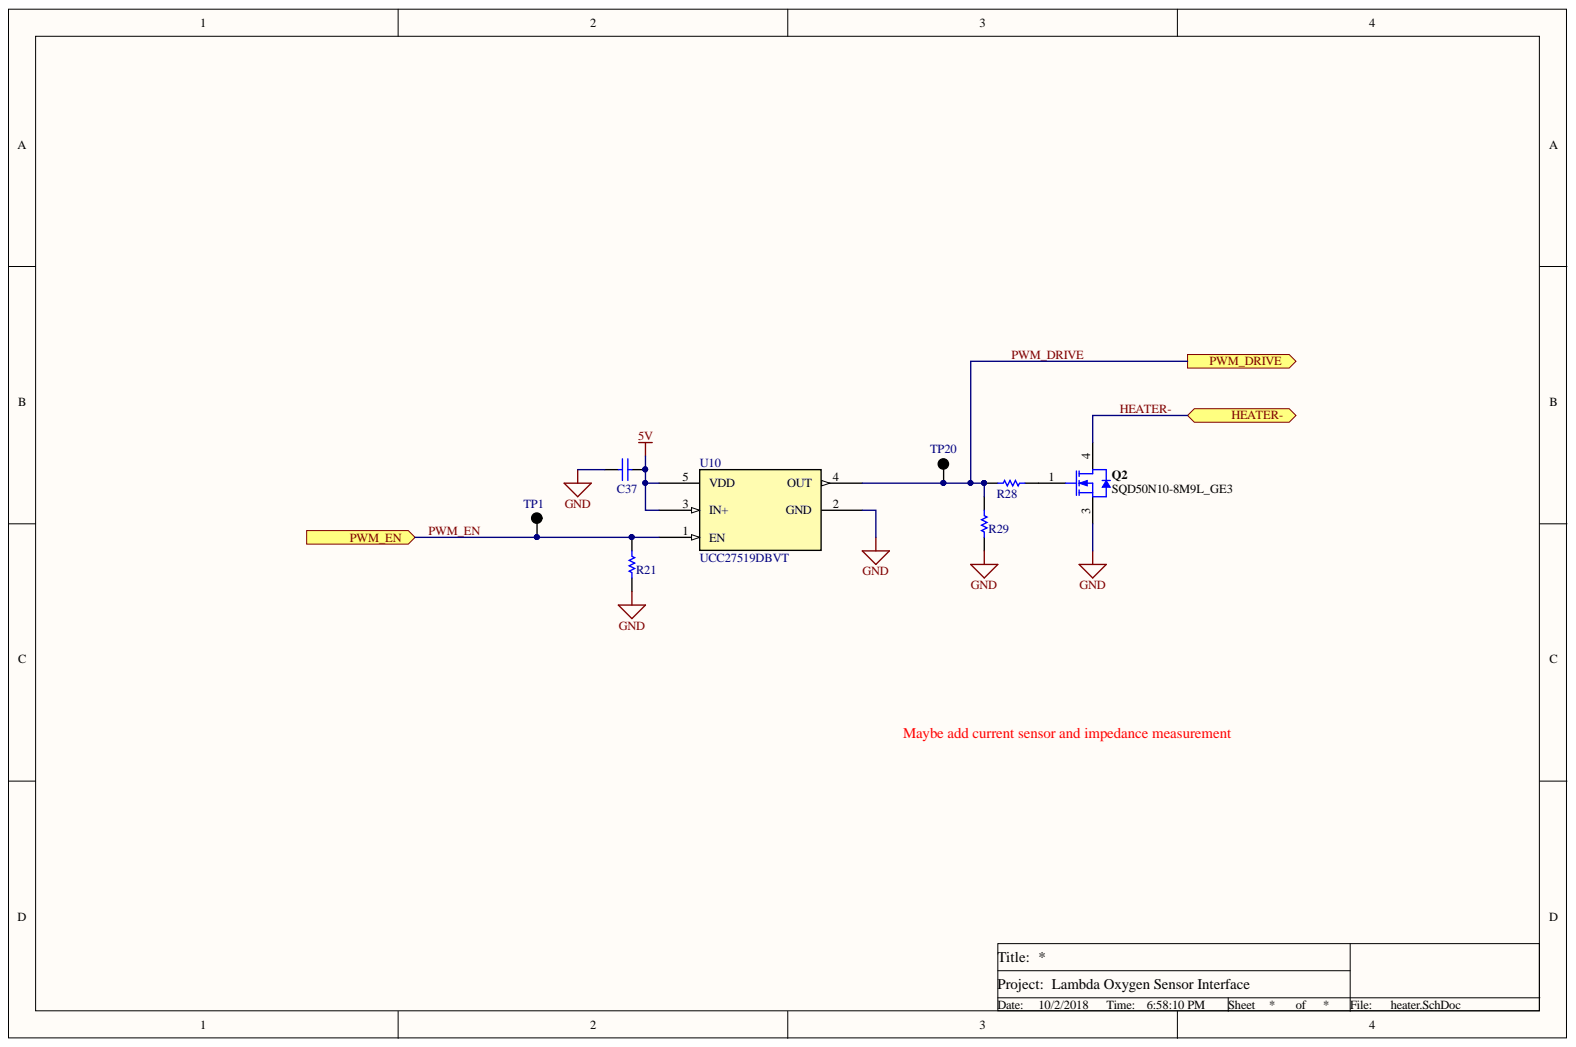
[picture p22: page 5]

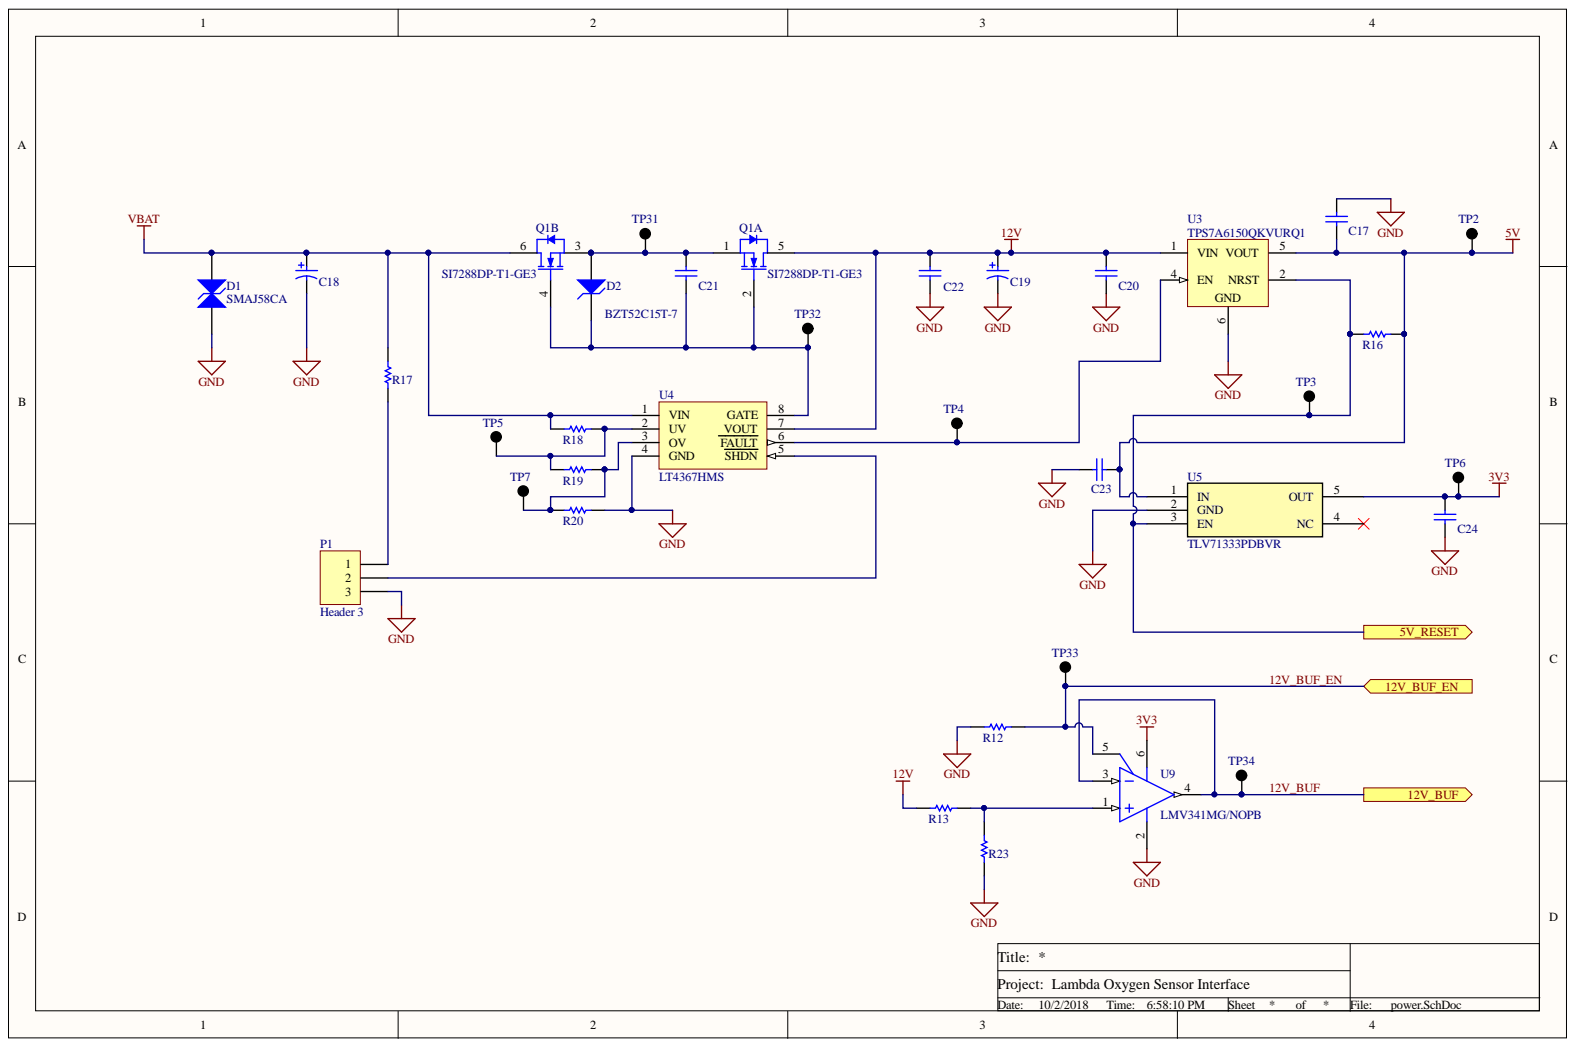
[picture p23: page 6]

Lambda Oxygen Sensor Interface





# Board S

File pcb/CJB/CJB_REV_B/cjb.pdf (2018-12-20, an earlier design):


12V_BUF SWDIO PWM_CUR SWCLK PWM_EN SWO NRST CJ125_SPI_SEL CJ125_SPI_SCK UART_TX CJ125_SPI_MISO UART_RX

CJ125_SPI_SCK HEATER-CJ125_SPI_MISO

CJ125_SPI_MOSI CJ125_UR CJ125_UA CJ_RESET CJ125_UN CJ125_VM CJ125_IA CJ125_IP | | CJ125_SPI_MOSI CJ125_UR DAC_OUT2 CJ125_UA CJ_RESET USB_DM USB_DP

BAT_FAULT
THEMO_CLK THERMO_SEL

THERMO_DAT

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

Lambda Oxygen Sensor Interface


hey are at a ver


te bead is seen as an i

te bead is seen as a resist

te bead has a impedance ar

te bead is seen as a capaci


All capacitors need to be close to their coresponding pins on U4.

OV 3
GND 4

TLS850D0TEV50 has a 425mV dropout voltage. Input range of 5.425V to
40V. Drive current of 500mA. 2% accuracy. +-20mV line regulation. Stable
with output capacitor of at least 1uF. Internal RO 20kOhm pull-up resistor.

LED has 2V forward voltage and 30mA continuous forward current. 1.5k
Ohm resistor limits LED current to 2mA.

LED resistor calculated with (5V - 2V) / 2mA = 1.5kOhm.

C26 needs to be close to the VOUT pin on U5.

The LTC4367 has an operating range of 2.5V
to 60V with protection for up to 100V,
consumes 70uA, fault recovery of 500us, UV
and OV thresholds of 500mV, shutdown
threshold of 1.2V, and open-drain fault
output. Gate pin output is 7.2V to 13.1V
greater than the input voltage.

R19, R20, and R21 set the undervoltage
threshold to 11.067V and overvoltage
threshold to 16.195V.

The SQJ974EP has dual n-channel MOSFET
with drain source voltage of 100V, drain
current of 30A, gate-source voltage of +-20V,
on-resistance of 25.5m Ohm, and gate
threshold of 2.5V.

All capacitors need to be close to their coresponding pins on U6.

TPS79933 has a 175mV dropout voltage. Input range of 3.475V to 6.5V.
Drive current of 200mA. 2% accuracy. 0.02%/V line regulation. Stable with
output capacitor of at least 2.2uF.

SMAJ58CA clips battery voltages to -58V
and +58V and operates up to 93V.

GND
100nF capacitor need to be within 2mm the VDD pin 1uF capacitor need to be within 100mm the VDD pin

LED has 2V forward voltage and 30mA continuous forward current. 680

BZT52C15T clips gate-source voltages to
15V preventing damage of the SQJ974EP.

LED resistor calculated with (3.3V - 2V) / 2mA = 680Ohm.

The 187k Ohm and 365k Ohm create a resistor divider that scales by 187/(187+768) = 0.19581.
The maximum expected input of 16.2V scales down to 3.172V to be read by the ADC.
The MCP6L01 acts as a unity gain buffer to provide the ADCs with low impedance inputs.

The 1nF C25 prevents the gate from
switching on or off too quickly.

Lambda Oxygen Sensor Interface


hen EN is at least 1



MPT-02-01-XX-X-RA-SD

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

The MCP6L01 boosts 3.3V input to 5V with R26 and R27 ceating a gain of 1 + (187 / 365) = 1.512V/V
An input of 3.3V has an output of 4.991V.

The 120k Ohm R28 is used to compensate for current through the negative terminal of the MCP6L01 and preventing the
voltage from changing. The compensation resistor required is equal to (365k * 187k) / (365k + 187k) = 123.65k Ohm. 120k
Ohm is the closest 5% resistor value.

Lambda Oxygen Sensor Interface






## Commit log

2018-05-27 Added stm32l4 starter code and docs
2018-05-27 Changed device include
2018-05-28 Switched code to use macros
2018-05-28 Started ADC functionality
2018-06-02 Worked on ADC a bit
2018-06-24 Added HAL library for low level drivers
2018-07-22 ADC functionality working
2018-09-06 Working DAC with HAL LL drivers
2018-09-07 Modified ADC to use LL HAL drivers
2018-09-08 Created function for all pin inits and removed higher level HAL drivers
2018-09-08 Setup pin init for the DAC
2018-09-08 Started basic SPI interface
2018-09-09 Added basic SPI functionality sans select line
2018-09-10 Initial PWM code
2018-09-11 Started CJ125 breakout board and fixed pcb branch
    [CJB.PrjPCB, INT.PrjPCB, breakout.schDoc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]
2018-09-11 Fixed cj125 breakout and added digital pulldowns
    [CJB.PrjPCB, breakout.schDoc, pcb.PcbDoc]
2018-09-12 Updated PWM hardware mappings
2018-09-18 Working on 2 layer board for everything
    [breakout.SchDoc, breakout.schDoc, cj125.schDoc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]
2018-09-19 Working PWM on PE11
2018-09-20 Finished schematic and started pcb routing
    [breakout.SchDoc, cj125.schDoc, cjb.PcbDoc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]
2018-09-26 Finished rev A and ordered from JLC
    [breakout.SchDoc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]
2018-10-02 Started revision B
    [breakout.SchDoc, cjb.PcbDoc, cjb.PrjPCB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]
2018-10-28 SPI corrections for conecting to CJ125
    [hw_map.c, hw_map.h, main.c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]
2018-10-29 Adjusted SPI to handle 16 bit values
2018-10-30 Added MATLAB script for lambda calibration
2018-11-01 Reverted SPI back to original transfer method.
    [spi.c]
2018-11-01 Return type for SPI transfer
2018-11-01 Updated UART to use hardware header
2018-11-01 Added Matlab calculations and CMSIS PID support
2018-11-02 Heater control working, UART working, DAC working
2018-11-07 Added lambda and temperatre lookup tables
2018-11-08 Qualifiers Code
    [temp.csv, v17Lambda.csv, v8Lambda.csv]
2018-11-26 PCB revision B and sims
    [LQFP64-10x10mm.stp, R_24.stp, breakout.SchDoc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]
2018-11-29 Corrections from doxygen changes
    [adc.c, main.c]
2018-11-30 Pin changes for PCB revision
2018-12-02 Created Rev C to fix problems in Rev B
    [breakout.SchDoc, cjb.PcbDoc, cjb.PrjPCB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]
2018-12-02 Fixed footprint of C1
    [cjb.PcbDoc, cjb.PrjPCB, sensor.schDoc]
2018-12-04 Added Current Sense support
2018-12-05 Initial current sense attempt
2018-12-06 Working current sense and heater initialization phase
2018-12-06 PID control experiments
2018-12-06 PID experiments, need to adjust scalars
2018-12-06 Fixed DAC channel output
    [hw_map.h, main.c]
2018-12-07 More PID testing
2018-12-11 PID tests, works but not the best
2018-12-11 Writing my own PID routine, and it works way better
2018-12-12 Wrote own PID routine
2018-12-12 PID coefficients that work well enough for now.
2018-12-12 Averaging the highest current sense voltages during condensation phase
2018-12-14 Attempting to read battery voltage at lowest using timer interrupts
2018-12-14 New calculations for lambda and temperature
2018-12-17 Corrections to lambda/temperature lookup calculations
    [main.c]
2018-12-18 Improved rev B schematic
    [breakout.SchDoc, cjb.PcbDoc, cjb.PrjPCB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]
2018-12-18 Added sims for heater drive circuit
2018-12-18 Started python script to read and graph uart data
2018-12-18 Worked on temperature and lambda cruve fitting
2018-12-18 Enable Derivative portion of PID control, although it's zero
2018-12-19 ADC now triggers a read on the rising edge of PWM signal
2018-12-19 Removing some interrupt code for adc and pwm
2018-12-19 Fixed python script in case of device restart
    [readdata.py]
2018-12-20 Final schematic changes
    [microcontroller.SchDoc, sensor.schDoc, thermocouple.SchDoc]
2018-12-20 Added PWM Vrms to plotting
2018-12-20 Plotting temperature curve fit
2018-12-20 Design Review Code printout
2019-02-20 Removed interrupt disables while reading the ADC
2019-03-18 Verification and recording of results
    [CalibrationCurrent.csv, DACOUTPUT.csv, DAC_air_comp.csv]
2019-04-09 Specification verification data
    [PureLambda.csv]
2019-04-10 Script to read data from sensor
2019-04-29 Cleaning up repo for final submission
    [temp.csv, v17Lambda.csv, v8Lambda.csv]
